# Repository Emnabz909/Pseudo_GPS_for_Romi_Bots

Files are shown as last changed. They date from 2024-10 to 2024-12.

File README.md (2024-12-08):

# Pseudo GPS for Romi Bots
Senior Project for Charlie Refvem by Emmanuel Baez, Gabriel Coria, Owen Guinane and Conor Schott

## Table of Contents
[Statement of Disclaimer](#statement-of-disclaimer)<br>
[Project Overview](#project-overview)<br>
[Concept Description and Justification](#concept-description-and-justification)<br>

## Statement of Disclaimer
Since this project is a result of a class assignment, it has been graded and accepted as a fulfillment of the course requirements. Acceptance does not imply technical accuracy or reliability. Any use of information in this report is at risk to the user. These risks may include catastrophic failure of the device or infringement of patent or copyright laws. California Polytechnic State University at San Luis Obispo and its staff cannot be held liable for any use or misuse of the project.   

## Project Overview
This project aims to develop a "pseudo-GPS" system that provides real-time, accurate location data to multiple Romi robots within a lab environment, since traditional GPS is ineffective indoors. Indoor localization technologies such as radar, ultrasonic sensors, and camera vision systems could offer valuable insights for this endeavor. Currently, ME 405 students work with Romi robots but lack access to absolute orientation and location data, which would enhance algorithm development. The design challenge is to create a prototype sensor to help students perform localization tasks more effectively. Key objectives include developing and testing a functional prototype by Fall 2024 if feasible, analyzing and documenting its accuracy, range, update rate, and latency, and providing comprehensive schematics and well-documented code to ensure the project can be continued seamlessly in the future. 

## Concept Description and Justification 
Mounted overhead, the camera captures images of the lab table, which are processed to generate a grid overlay in 2-dimensional space, facilitating precise localization and differentiation of objects. The device creates an origin point on the table, which it uses to measure Romi bots and obstacles relative to it. It constantly monitors Romi bots and obstacles within its field of view. Data such as grid representation and object positioning are handled by our microcontroller for processing. 

To aid the microcontroller with processing, we will develop custom libraries tailored to recognize specific objects in the environment, including the Romi robots, table, and obstacles. Instead of training models through Teachable Machine, we will use Aruco markers, which function similarly to QR codes, to identify and track each object. 

We are confident that our hardware will be able to meet the project specifications. By using trigonometry and the manufacturer-given data on the camera modules, we can estimate an accuracy of 0.55 mm per pixel for the Raspberry Pi Camera Module 3 and an accuracy of 1mm per pixel with the Raspberry Pi Camera Module 3, assuming a mounting height of 6.75ft above the table. This falls well-within our target accuracy of +- 5mm for Romi tracking.

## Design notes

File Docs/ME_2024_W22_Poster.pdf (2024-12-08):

# Pseudo GPS for Romi Bots

## Team members: Emmanuel Baez, Gabriel Coria, Owen Guinane, Conor Schott

B

# MECHANICAL ENGINEERING

The image above shows the camera setup, which will be mounted on the classroom roof. This location ensures the camera can see the entire space, allowing it to easily track the movement of the Romi robots.

The image above shows a Romi Robot with an ArUco marker attached to the top. This marker helps us track the robot’s location and movement, making it easier to monitor its actions and interactions in real-time.

This test demonstrates how ArUco markers can be used to track positions in space. One marker is set as the origin, while other markers are tracked based on their coordinates, calculated from the camera's view using pixel data. In this test, the markers remain stationary to show how their positions can be accurately identified and mapped.

## Testing for Position and Orientation

## Classroom Setup

## Romi with ArUco Marker

Our final design securely holds the Raspberry Pi and Pi Camera in place. The 3D-printed mount is designed to be easily attached to a ceiling tile using toggle bolts, ensuring a stable and adjustable installation.

## Final Design

## Conceptual Idea

## Camera Spec Analysis

## Problem Statement

To verify that our camera is capable of tracking within our +- 5mm accuracy target, we can use our Field of View (FOV) specifications provided by the camera manufacturer as well as the known height the system will be mounted to the ceiling to estimate the viewing area of the camera. If the viewing area can fully capture the table, then we can use the digital resolution of the camera as well as the viewing area to determine the number of mm per pixel. If this is less than 5mm, the camera will be suitable for this application.

The project involves using an overhead camera to monitor a lab table. The camera captures images, which are processed by a microcontroller to track objects relative to a defined origin on the table. Custom libraries will reference objects like the Romi bots and obstacles, with computer vision tools like the ArUco markers to improve object recognition.

Object localization are handled through OpenCV, which detects object contours and calculates their coordinates relative to the grid’s origin. The system uses ArUco markers placed on the Romi bots or obstacles for precise identification and orientation, improving localization accuracy. The system continuously captures video for real-time monitoring, with detected objects localized and used for movement control to avoid obstacles.

## List of Acknowledgement

### - Charlie Refvem

### - Dr. Amanda Emberley

### - Dr. John Ridgely

### - Dr. Jonathan Ventura

The Romi robots in the Cal Poly Mechatronics lab currently can't determine their exact position or orientation using their own sensors. To help develop more advanced technology, ME 405 instructor Charlie Refvem and his students need a system that can provide accurate, real-time location data for multiple Romi robots. This solution will improve how the robots track each other and communicate, ensuring high accuracy, precision, and fast updates over a wide range with minimal delay.

The lack of indoor localization technology limits ME 405 students’ ability to gather precise position data on the Romi robot, restricting their development of advanced algorithms.

## Objective

Distance Test @ Various Heights
| Computer | Actual | z [mm]
Run 1 | x [mm] | 86 | 81 | 15
| y [mm] | 369 | 370
Run 2 | x [mm] | 605 | 590 | 113
| y [mm] | 202 | 190
Run 3 | x [mm] | 536 | 534 | 50
| y [mm] | 378 | 380
Run 4 | x [mm] | 24 | 35 | 113
| y [mm] | 53 | 60
Run 5 | x [mm] | 117 | 122 | 50
| y [mm] | 460 | 463

Distance Test @ Constant Heights Markers placed on Romi (z = 105mm)
| | Computer | Actual
Run 1 | x [mm] | 310 | 296
| y [mm] | 95 | 85
Run 2 | x [mm] | 192 | 178
| y [mm] | 339 | 330
Run 3 | x [mm] | 232 | 225
| y [mm] | 144 | 150
Run 4 | x [mm] | 208 | 195
| y [mm] | 231 | 220
Run 5 | x [mm] | 141 | 135
| y [mm] | 232 | 215

Distance Test @ Constant Heights Markers placed on Romi (z = 0mm)
| | Computer | Actual
Run 1 | x [mm] | 7 | 0
| y [mm] | 392 | 361
Run 2 | x [mm] | 89 | 90
| y [mm] | 2 | 0
Run 3 | x [mm] | 139 | 137
| y [mm] | 46 | 42
Run 4 | x [mm] | 35 | 30
| y [mm] | 236 | 242
Run 5 | x [mm] | 455 | 443
| y [mm] | 248 | 255

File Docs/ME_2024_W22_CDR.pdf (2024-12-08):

Romi GPS | 1

Critical Design Review (CDR) report

# Pseudo GPS for Romi Critical Design Review

May 2, 2024

For Charlie Refvem

Team
Emmanuel Baez – embaez@calpoly.edu Gabriel Coria – gacoria@calpoly.edu Owen Guinane – oguinane@calpoly.edu Conor Schott – cjschott@calpoly.edu

College of Engineering
California Polytechnic State University, San Luis Obispo 2024

## Table of Contents

## Statement of Disclaimer

Since this project is a result of a class assignment, it has been graded and accepted as a fulfillment of the course requirements. Acceptance does not imply technical accuracy or reliability. Any use of information in this report is at risk to the user. These risks may include catastrophic failure of the device or infringement of patent or copyright laws. California Polytechnic State University at San Luis Obispo and its staff cannot be held liable for any use or misuse of the project.

## Four Panel Chart

Table 1. Four-Panel Chart
Project Overview
- Project Objective: Currently, the Romi robots used in the Mechatronics lab have no way of obtaining absolute orientation or location from onboard sensors. The Cal Poly ME 405 instructor, Charlie Refvem, and Mechatronics students need a way to deliver precise and real-time location data for multiple Romi robots for the development of better algorithms. Our aim is not just to improve tracking but also to enhance communication standards among multiple Romis by ensuring geolocation accuracy, precision, range, latency, and update rates.
- Documentation and Impact: The project involves comprehensive documentation, including detailed electrical schematics and code explanations.

Concept Description

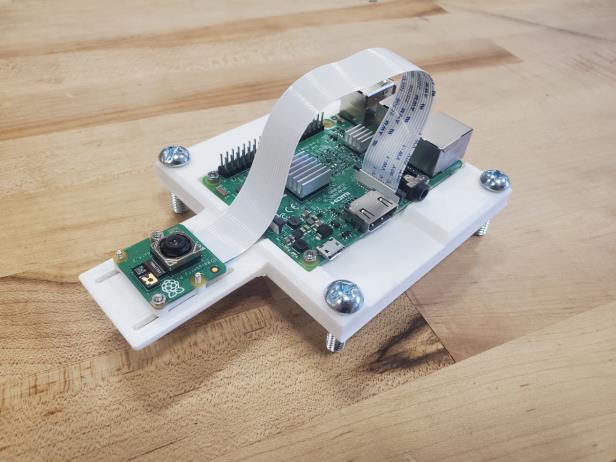
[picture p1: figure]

The idea with our structural prototype is to prove that our system will be able to detect the Romi bots as well as that it will properly mount to a ceiling tile. In the picture above is our Raspberry Pi and Camera Module wired together ready to be used.

Concept Justification

The decision to integrate camera technology into the project is based on its accuracy, providing precise locational data within ±5mm. The Raspberry Pi camera’s real-time data capabilities and fast update rate enable monitoring of multiple Romi robots. Additionally, the camera's cost-effectiveness and plentiful documentation online further supports its selection for enhancing tracking capabilities.

What’s Next

This quarter we will have to keep working on our software to get the detection to work, as well as implementing a grid system to help with the position of the Romi bots. We will perform multiple pass/fail tests on the detection and position and safety tests with our system mounted. The safety test for mounting the system will consist of FEA on our ceiling tile, and a shake test to see if the system will fall.

## Overview

We have finalized the concept selection and are currently expanding further iterations on our concept prototype. This report aims to describe our chosen concept, our reasoning behind it, and a table of the alternate solutions considered. In addition, this report also includes a preliminary analysis, a weighted design matrix, an updated Gantt chart, a design hazard matrix, and our references. We hope to get feedback on our reasoning for the sensor choice and on the housing system.

## Concept Description and Justification

For our system, we decided to use a Raspberry Pi with a camera to obtain absolute orientation and positional data. The basic layout is depicted in Figure 1 below.

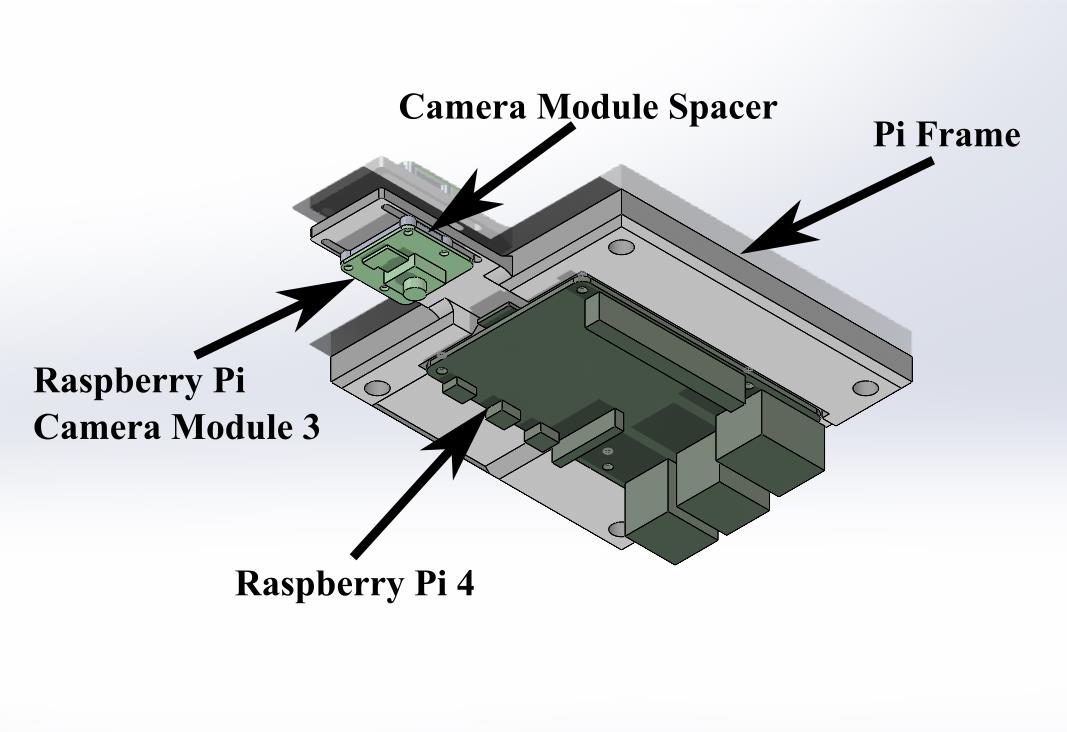
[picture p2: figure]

Figure 1. General layout of system

Mounted overhead, the camera captures images of the lab table, which are processed to generate a grid overlay in 2-dimensional space, facilitating precise localization and differentiation of objects. The device then creates an origin point on the table, which it will use to measure Romi bots and obstacles relative to it. It will constantly monitor Romis and obstacles within its field of view. Data, such as grid representation and object positioning will be handled by our microcontroller for processing. Through various algorithms, the microcontroller categorizes objects based on predefined characteristics and determines their relative locations with a precision of ±5mm, utilizing image processing techniques like object recognition and spatial mapping to track and locate Romis and obstacles in real-time, ensuring current and reliable tracking data.

The software integrates computer vision and machine learning techniques to detect Romis, obstacles, and the table. Initially, essential components such as the COCO dataset's class names and the SSD MobileNet V3 model configuration are imported. This setup enables the system to recognize a wide range of objects with high precision. Upon initialization, the detection model is configured with specific parameters for optimal performance. During operation, the software continuously captures frames from the overhead camera feed and undergoes object detection using the pre-trained SSD MobileNet V3 model. Detected objects are identified based on their confidence scores and class labels, and bounding boxes are drawn around them for visualization. Simultaneously, the software establishes a grid overlay on the detected table and defines an origin point, facilitating precise localization and measurement of objects within the environment. Coordinates of Romis and obstacles relative to the table's origin are then transmitted to the microcontroller for further processing and monitoring. Through the integration of object detection, grid generation, and coordinate calculation functionalities, the software ensures accurate detection and monitoring of Romis and obstacles.

## Safety

To ensure the safe operation of our system, several main concerns need to be addressed. The largest safety concern with our system comes with mounting. Because the system is roof-mounted, we need to design the system to be mounted securely and minimize the chance of falling out, due either to structural failure of mounting parts or by not fitting properly within a drop-down roof tile frame. To ensure this does not occur, we plan on performing finite-element analysis on the mounting hardware to verify that it can hold the entire weight of the system with a safety factor of 5. Minor safety considerations include adding fillets and chamfers to 3-D printed parts to eliminate sharp corners and edges which can cut the user when handling.

## Justification Table

Table 2. Justification Table

Spec # | Specification Title | Specification Description | Target (units) | Justification
1 | Total System Length | The system would prefer to be able to fit onto a Romi. | Romi Size | Currently, we plan to attach an ESP32 module to the Romi bots for communication. Our sponsor has approved.
2 | Total System Weight | The Romi will also have other sensors attached to it, so we would not want to encumber it further. | 2 lbs. | Currently, we have plans to attach an ESP32 module to the Romi bots for Communication, and our sponsor said it's okay.
3 | Field of View | The system should track a Romi placed on the classroom table. | 96x48 in. | The Raspberry Pi Camera 3 modules have a wide enough field of view to capture the table in its entirety, depending on the mounting distance.
5 | Data Transfer | The system should be able to transfer data at a high rate. | 6 Hz | The Raspberry Pi 4 that we purchased has the specs to transfer data at 6 Hz.
6 | Number of Romis being detected | The system should be able to track multiple Romis | 6 bots | Our tracking camera algorithm combined with the camera positioning will be able to track 6 Romis.
7 | Tracking Resolution | The system should be able to track the position of Romi. | +/- 5 mm | The Raspberry Pi Camera 3 modules will have enough resolution to track Romi position.
8 | Production Cost | The budget is $500. (could be higher) | $500 | We have an Excel that we put in every purchase to make sure we are within budget and notify our sponsor when we need to make a purchase.

## Appendix

## Updated Gantt Chart

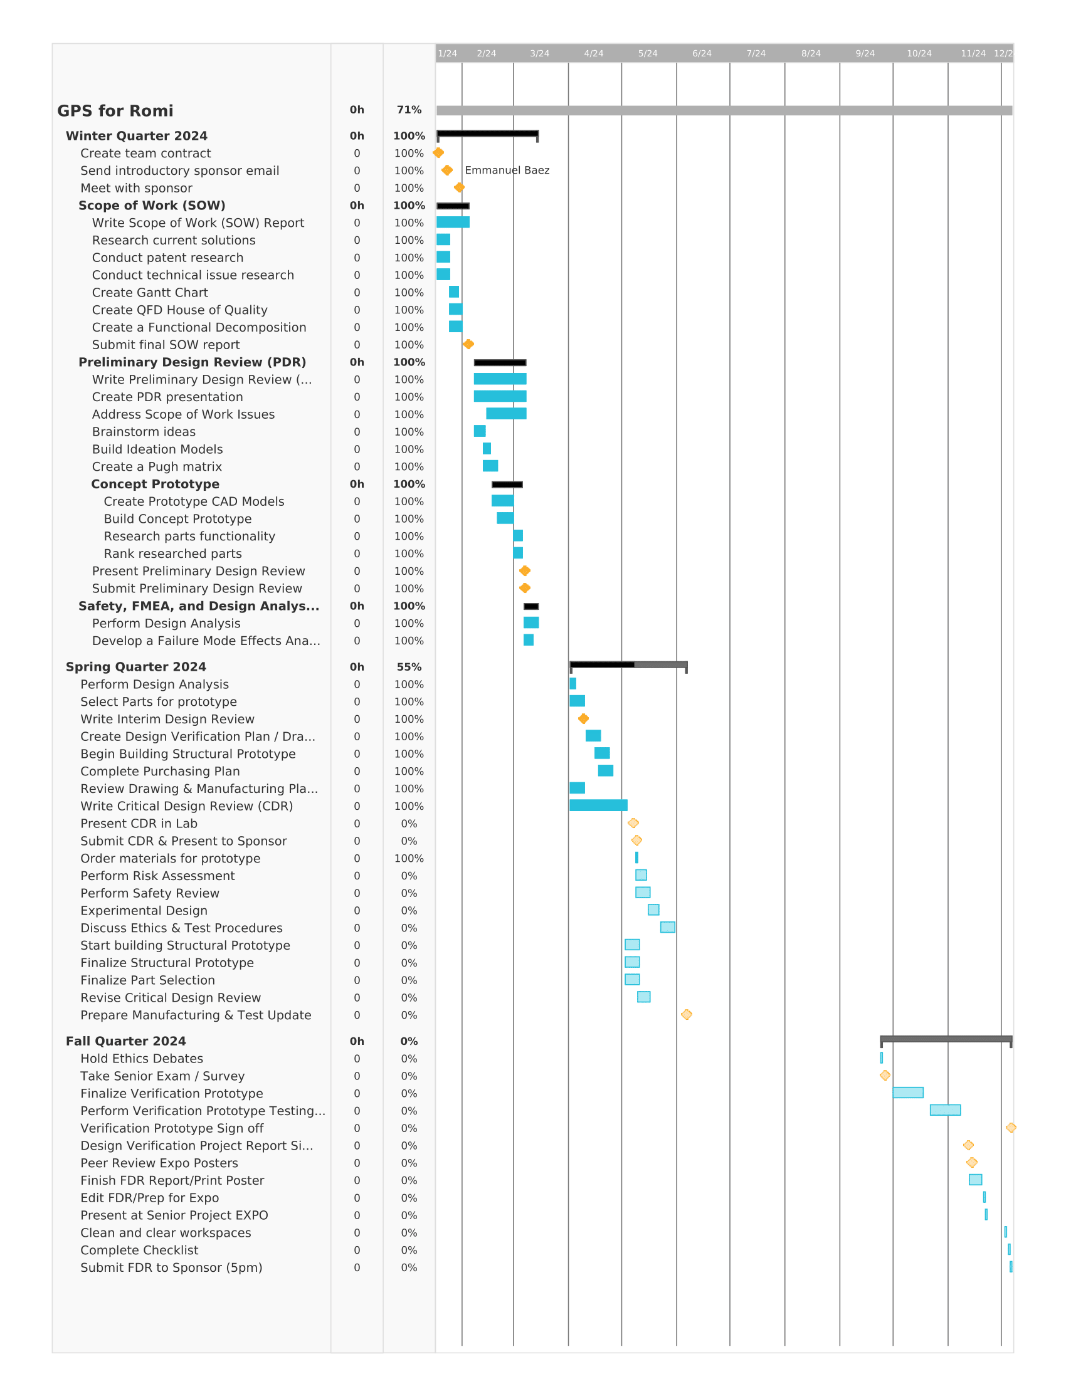
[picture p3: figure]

## Design Hazard Checklist

Table 4. Design Hazard Checklist Table

Y | N
| N | 1. Will any part of the design create hazardous revolving, reciprocating, running, shearing, punching, pressing, squeezing, drawing, cutting, rolling, mixing or similar action, including pinch points and sheer points?
| N | 2. Can any part of the design undergo high acceleration/deceleration?
| N | 3. Will the system have any large moving masses or large forces?
| N | 4. Will the system produce a projectile?
Y | | 5. Would it be possible for the system to fall under gravity creating injury?
Y | | 6. Will a user be exposed to overhanging weights as part of the design?
| N | 7. Will the system have any sharp edges?
| N | 8. Will any part of the electrical systems not be grounded?
| N | 9. Will there be any large batteries or electrical voltage in the system above 40 V?
| N | 10. Will there be any stored energy in the system such as batteries, flywheels, hanging weights or pressurized fluids?
| N | 11. Will there be any explosive or flammable liquids, gases, or dust fuel as part of the system?
| N | 12. Will the user of the design be required to exert any abnormal effort or physical posture during the use of the design?
| N | 13. Will there be any materials known to be hazardous to humans involved in either the design or the manufacturing of the design?
| N | 14. Can the system generate high levels of noise?
| N | 15. Will the device/system be exposed to extreme environmental conditions such as fog, humidity, cold, high temperatures, etc?
| N | 16. Is it possible for the system to be used in an unsafe manner?
| N | 17. Will there be any other potential hazards not listed above? If yes, please explain on reverse.

## Manufacturing Plan

Table 5. Manufacturing Plan table

Sub system | Component | Purchase (P) Modify (M) Build (B) | Raw Materials Needed to make/modify the part (only M & B) | Where/how procured? | Equipment and Operations anticipate using to make the component | Key limitations of this operation places on any parts made from it
Ceiling Mount | Ceiling Tile | M | Ceiling Tile | Provided by Wood Workshop at Cal Poly for use in Lab 192-118 | 11/16" Drill Bit, Cordless Drill to make holes that the threaded inserts will screw into. | n/a
| 1/4"-20 Zinc Plated Insert Nut | P | n/a | Purchased at Home Depot | n/a | n/a
Housing | Main Housing | B | PLA Plastic | 3D printed | 3D Printer to create the housing, M2.5 x .45, 1/4"-20 tap drill bit and a tap s to create internal threads on the large outer holes and small inner holes. Deburring may be necessary after tapping. | Small size may prevent M2.5 holes from printing properly. Additional drilling may be required
| 1/4"-20 1" Machine Screws | P | n/a | Purchased at Home Depot | n/a | n/a
| M2.5 10mm Screws | P | n/a | Purchased from Amazon | n/a | n.a
| M2 10mm screws | P | n/a | Purchased from Amazon | n/a | n/a
Microcontrolle r | Raspberry Pi 4 Model B | P | n/a | part already provided by sponsor (Adafruit) | n/a | n/a
| Micro HDMI Cable | P | n/a | part already provided by sponsor (Adafruit) | n/a | n/a
| SD card | P | n/a | part already provided by sponsor (Adafruit) | n/a | n/a
| Heat Sink | P | n/a | part already provided by sponsor (Adafruit) | n/a | n/a
| Power Supply | P | n/a | part already provided by sponsor (Adafruit) | n/a | n/a
Camera | Raspberry Pi Camera Module 3 | P | n/a | part already provided by sponsor | n/a | n/a
| Camera Spacer | B | PLA Plastic | 3D printed | 3D Printer to create the part | Small Size may prevent M2 holes from printing to size. Screws may have to be threaded through.

Manufacturing Steps
Ceiling Tile Assembly
Ceiling Tile (110)
11/16” Drill Bit with Cordless Drill
1. Drill four holes that are 11/16” in diameter on the top (floor-facing) side of the ceiling tile to allow the threaded inserts to screw in.
2. Screw 1/4”-20 Zinc Plated inserts into drilled holes. These will connect the main housing to the ceiling tile.

Housing Assembly
Main Housing (210)
3D Printer
1. Using the provided file “MainHousing.STL”, use a 3D printer to print the housing. Refer to printer documentation for instructions on how to print an STL file.
1/4"-20 Tap drill bit and Tap
2. On the larger outer 4 holes and center hole, tap these holes all the way through. These holes will secure the housing to the ceiling tile.
M2.5 x 45 Tap drill bit and Tap
3. On the smaller inner 4 holes, tap these holes all the way through. These will be used to secure the Raspberry Pi 4 to the housing.

Camera Assembly
Camera Spacer (2320)
3D Printer
1. Using the provided file “CamSpacer.STL”, use a 3D printer to print the spacer. Refer to printer documentation for instructions on how to print an STL file.

Assembly instructions
1. Screw the Camera Spacer (2320) to the slots of the Main Housing (210) using four M2 10mm Machine Screws (250) so that camera spacer is on the top side of the part and the threads are facing upward.
2. Insert the MicroSD Card (2220) into the Raspberry Pi 4 (2210) to make the Microcontroller Assembly.
3. Screw the Microcontroller Assembly (220) into the main housing with four M2.5 10mm Machine Screws (250) until it is finger tight. Over-tightening the screw may cause damage to the board.
4. Insert the Raspberry Pi Camera Module 3 (2310) on the threads of the M2 Machine Screws. Use M2 Nuts (270) to secure the camera to the spacer.
5. Connect the camera module to the Raspberry Pi 4 using the module’s ribbon cable.
6. Use a 6mm hex key to screw the threaded inserts (120) into the ceiling tile to make the Ceiling Tile Assy (10).
7. Using the four 1/4” – 20 1” Machine Screws (240), screw the Main Housing to the holes in the Ceiling Tile Assy (10) to create the Final Assembly (1).
8. Install the Final Assembly in place of a similar ceiling tile or empty ceiling tile frame over desired tracking area.
9. Connect Power Supply (31) and Micro HDMI (30) cables as needed.

## Design Manufacturing Plan

Table 3. Design Verification Plan Table
Planned Test | What it will test (user need or specific spec, whichever is most applicable for your project and sponsor) | Required resources
Detection Test | Test to see if the code runs with no errors and if the camera displays a picture while detecting objects. | Raspberry Pi, camera, computer
Ceiling Mount Test | Testing to inspect whether the hardware will stay on the ceiling | Ceiling tile, Raspberry Pi, Housing, Camera
Rate of Transfer test | Test to see how fast the data from the Raspberry Pi is transferred to a computer. | Raspberry Pi, Computer
Fitment and Weight test | Test to ensure that ESP32 module will fit comfortably on the Romi robots without encumbering them | ESP32 Module, Romi Robots
Resolution test | Test to determine how accurate the camera can track a single Romi Robot with a target accuracy of | Romi Robot, Final assembly, computer
Swarm detection test | Test to ensure that system is capable of tracking multiple Romi robots simultaneously without issues. | Romi Robots, Final Assembly, Computer

## Budget

Table 6. Budget Chart

### Romi Budget Plan

Part | Cost ($)
Micro HDMI to HDMI cable | 8.95
Raspberry Pi Camera Module 3 Standard - 12MP Autofocus | 25
Raspberry Pi 4 model B-8GB RAM x2 | 150
Official Raspberry Pi Power Supply 5.1V 3A with USB C | 7.95
SD/MicroSD Memory Card - 16GB Class 10 - Adapter Included | 19.95
Official Raspberry Pi 4 Case Fan and Heatsink | 5
Parts Total | 216.85
Initial Budget | 500
Current Budget | 283.15

## Idented Bill of Materials

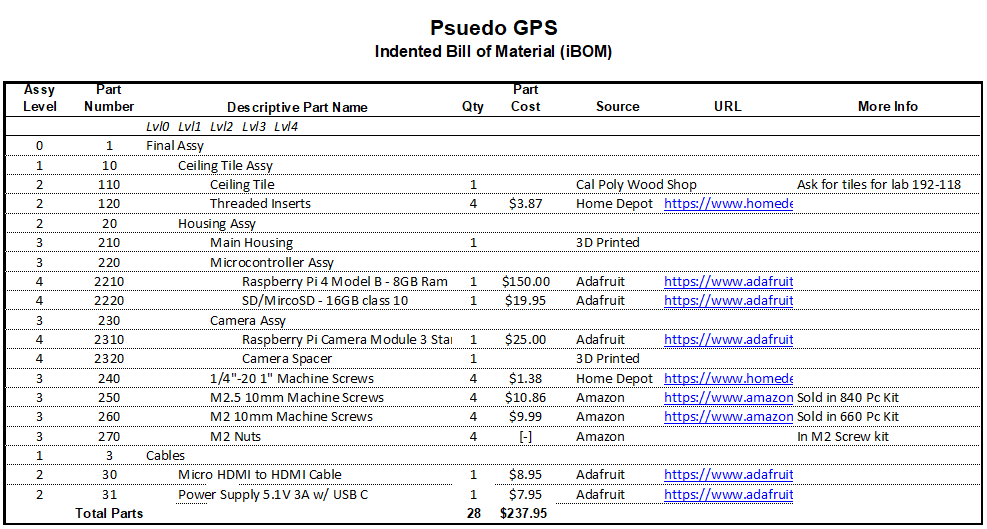
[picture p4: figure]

Figure 2. Indented Bill of Materials (iBOM)

## Supporting Evidence

We can confirm that our field of view and tracking resolution will meet our specifications by performing an analysis of the camera’s field of view. For a camera, we have two types of viewing distances that define our viewing area, horizontal distance Dhor and vertical distance Dvert. In our desired configuration where the camera system is mounted to the roof and facing down, we can calculate the viewing area using trigonometry.

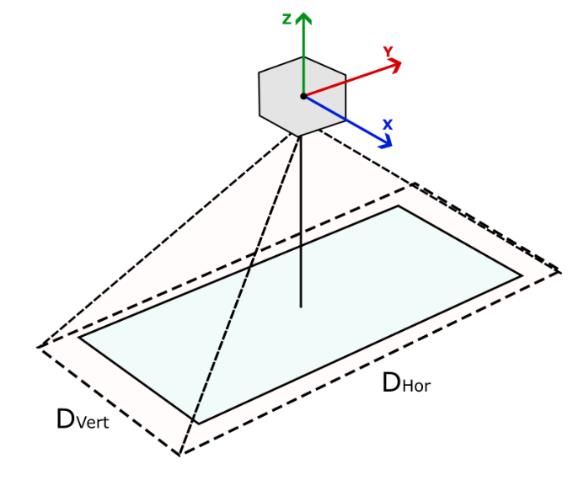
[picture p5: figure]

Figure 3. 3D Sketch of camera setup.

Camera manufacturers specify the horizontal and vertical angles for the field of view for any given lens which we’ll define as HFOV for the horizontal field of view and VFOV for the vertical field of view. Let’s take the case of the horizontal field of view. Assuming a perfectly centered camera, we can model it as a symmetrical triangle of angle HFOV, height Hmount, and distance Dhor. Hmount will be the height at which the system is mounted above the table.

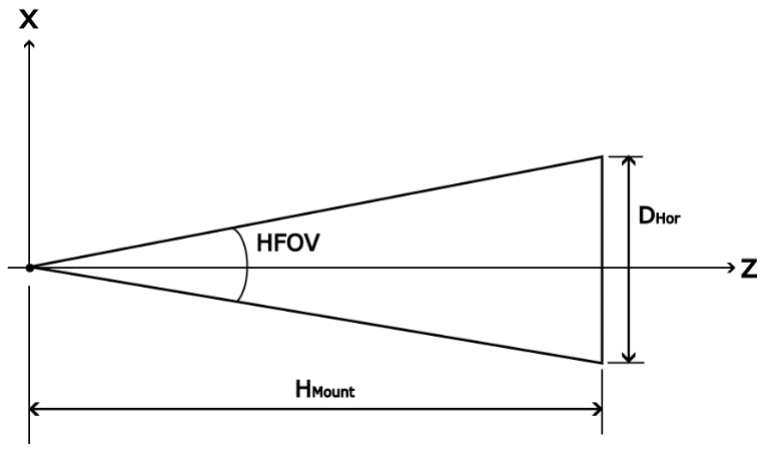
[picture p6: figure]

Figure 4. Viewing triangle of camera for horizontal distance

Since the triangle is isosceles, we can split it into two identical right triangles with half the angle and horizontal distance.

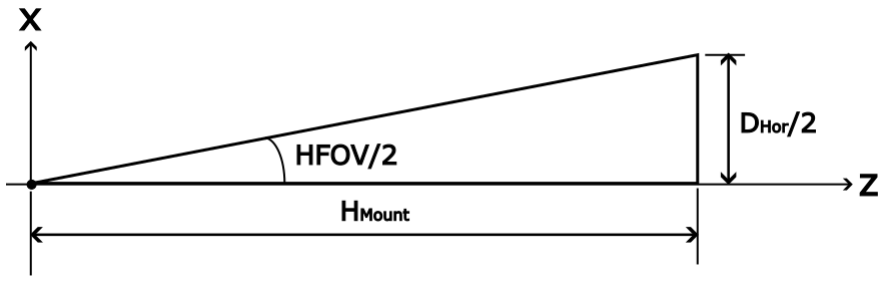
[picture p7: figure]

Figure 5. Half of viewing triangle. Trigonometry can now be used to solve for distance.

Using trigonometry, we obtain
tan (

HFOV
2

) =

(DHor/2)

(Hmount)
Rearranging the equation,

DHor = 2Hmount tan (

HFOV
2

)

Solving for the vertical distance DVert follows a similar process, so similar equation can be used.
DVert = 2Hmount tan (

VFOV
2

)

To track the whole table, the camera must have a vertical viewing distance of at least 4 feet and a horizontal viewing distance of 8 feet. Using these two distances, we can calculate the viewing area of the camera.
AView = DHor ∗ DVert
Finally, by dividing the viewing area by the pixel count, we can determine the area of each pixel in the image, which will be our tracking resolution area.

Apix =

AView
# ofPixels

A pixel is a square, so using the area of the pixel, we can determine the pixel width, which will be our tracking resolution.
Wpix = √Apix

Now that we have our basic equation, we can substitute our values to determine if our cameras will meet specifications. Measurements taken in the lab give us a maximum mounting height of 7 ft above the table. Accounting for the fact that our camera will not sit flush with the drop-down ceiling, we can assume a reasonable mounting distance of 6.25 ft above the table. To streamline the process of calculating viewing areas, we used an Excel worksheet to run the calculations

Table 7. Camera Calculation
Camera /Lens | Resolution | HFOV | VFOV | Dhor | Dvert | Aview | Apix | Wpix
[pixels] | [deg] | [deg] | [ft] | [ft] | [ft^2] | [mm^2] | [mm^2 ] | [mm]
Raspberry Pi Camera Module 3 | 1.19E+07 | 66 | 42 | 8.12 | 4.80 | 39.0 | 3.62E+0 6 | 0.30 | 0.55
Raspberry Pi Camera Module 3 Wide | 1.19E+07 | 102 | 67 | 15.44 | 8.27 | 127.7 | 1.19E+0 7 | 1.00 | 1.00

From our analysis, it appears that both the Raspberry Pi camera module 3 and Raspberry Pi Camera Module 3 wide will both meet our design specifications.

The ESP32 effectively communicates with our Pi4’s Wi-Fi module, ensuring seamless connectivity. Its integration with the Romi Nucleo board, equipped with GPIO pins, ADC, and PWM, facilitates data transmission to and from the Pi4. With low power consumption, especially when powered by the Nucleo, it enables smooth continuous tracking and monitoring tasks. Costing between $10 to $15, the ESP32 offers a cost-effective solution. Its compact dimensions (55mm x 27.9mm x 25mm) and lightweight construction (less than 1 ounce) ensure minimal impact on the Romi's weight distribution.

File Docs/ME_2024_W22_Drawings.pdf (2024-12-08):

# Pseudo GPS for Romi Drawing & Specification Package

May 10, 2024

For Charlie Refvem

Team

Emmanuel Baez – embaez@calpoly.edu

Gabriel Coria – gacoria@calpoly.edu

Owen Guinane – oguinane@calpoly.edu

Conor Schott – cjschott@calpoly.edu

College of Engineering

California Polytechnic State University, San Luis Obispo

2024

# Indented Bill of Materials

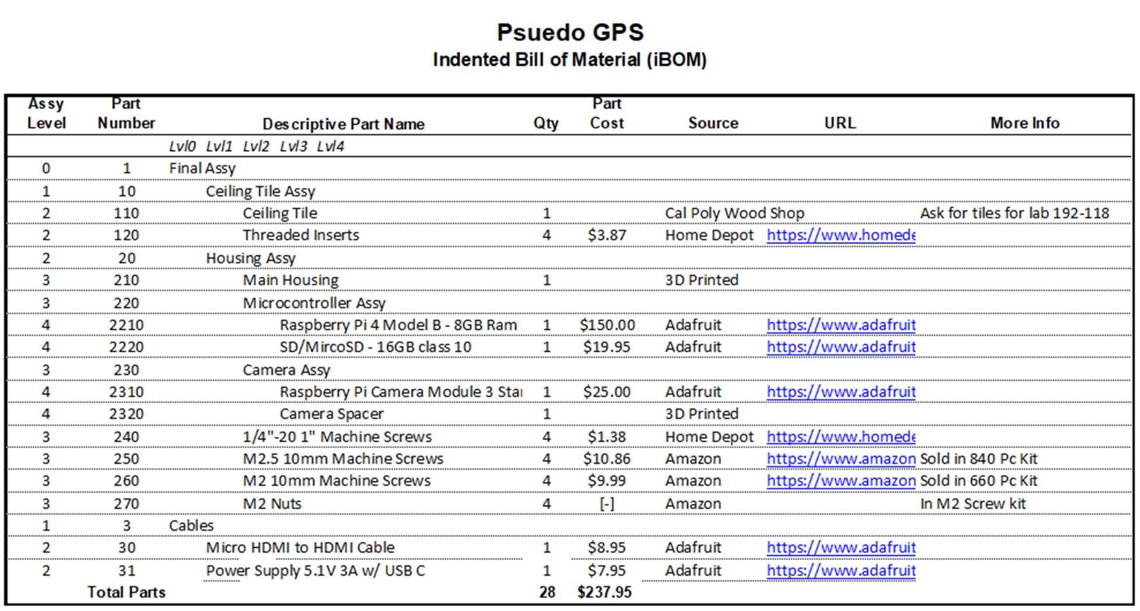
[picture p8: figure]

# Purchased Parts Table

Part # | Part Name | Vendor | Vendor's Part # | Price | Manuf. | Manuf. Part # | Key Features/ Specs | URL
120 | 1/4"-20 Zinc Plated Insert Nut | Home Depot | 20427422 2 | $3.87 | Everbilt | 801884 | 1/4" Diameter, 20 TPI, 3/4" Depth, Steel, Zinc Plated | https://www.homedepot.com/p/Everbilt-1-4-in-20-Zinc-Plated-Insert-Nut-4-Pack-801884/204274222
2210 | Raspb erry Pi 4 Mode l B | Adafruit | 4564 | $150. 00 | Raspber ry Pi | N/A | Microcontrolle r | https://www.adafruit.com/product/4564
2220 | 16GB Micro SD Card | Adafruit | 2693 | $19.9 5 | SanDisk | N/A | 16GB MicroSD card | https://www.adafruit.com/product/2693
2310 | Raspb erry Pi Came ra Modu le 3 | Adafruit | 5657 | $25.0 0 | Raspber ry Pi | N/A | 12MP, | https://www.adafruit.com/product/5657

240 | 1/4"-20 1" Mach ine Screw s | Home Depot | 20427464 4 | $1.38 | Everbilt | 803481 | 1/4" Diameter, 20 TPI, 1" Length, Steel, Zinc Plated, Round head philips machine screw | https://www.homedepot.com/p/Everbilt-1-4-in-20-x-1-in-Zinc-Plated-Combo-Round-Head-Machine-Screw-4-Pack-803481/204274644
250 | M2.5 10m m Mach ine Screw s | Amazon | B0CRRC YZHS | $10.8 6 | qiwuhai | N/A | M2.5, 304 Stainless Steel, Lengths ranging from 4-25mm, 40 screws for each size, half flathead, half hex button | https://www.amazon.com/dp/B0CRRCYZHS/ref=twister_B0CHMKL1DF?_encoding=UTF8&th=1
260 | M2 10m m Mach ine Screw s | Amazon | B0B93G1 H9L | $9.99 | Kadrick | N/A | M2, 304 Stainless Steel, Lengths ranging from 4mm to 16mm, 660 pc total | https://www.amazon.com/Kadrick-Assortment-Button-Stainless-Washers/dp/B0BX96SMW4?ref_=ast_sto_dp&th=1&psc=1
270 M2 | Nuts | Amazon | N/A | N/A | Kadrick | N/A | Comes in Kadrick M2 Kit, 220 pc count
30 | Micro HDM I to HDM I Cable | Adafruit | 1322 | $8.95 | Adafruit | N/A | 2 meters length, HDMI 1.3 to MicroHDMI | https://www.adafruit.com/product/1322
31 | Powe r Suppl y 5.1V 3A w/ USB C | Adafruit | 4298 | $7.95 | Raspber ry Pi | N/A | 1.5 meters length, 5.1V, 3A Output, USB-C | https://www.adafruit.com/product/4298

# Main Assembly Drawing

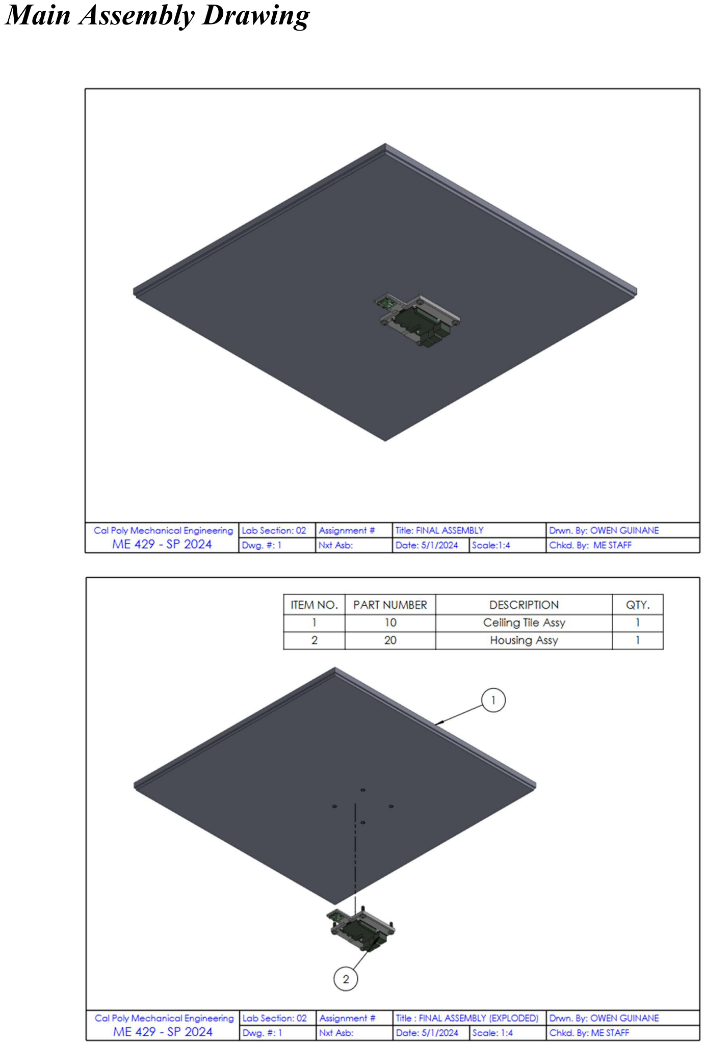
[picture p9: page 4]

# Ceiling Tile Assy

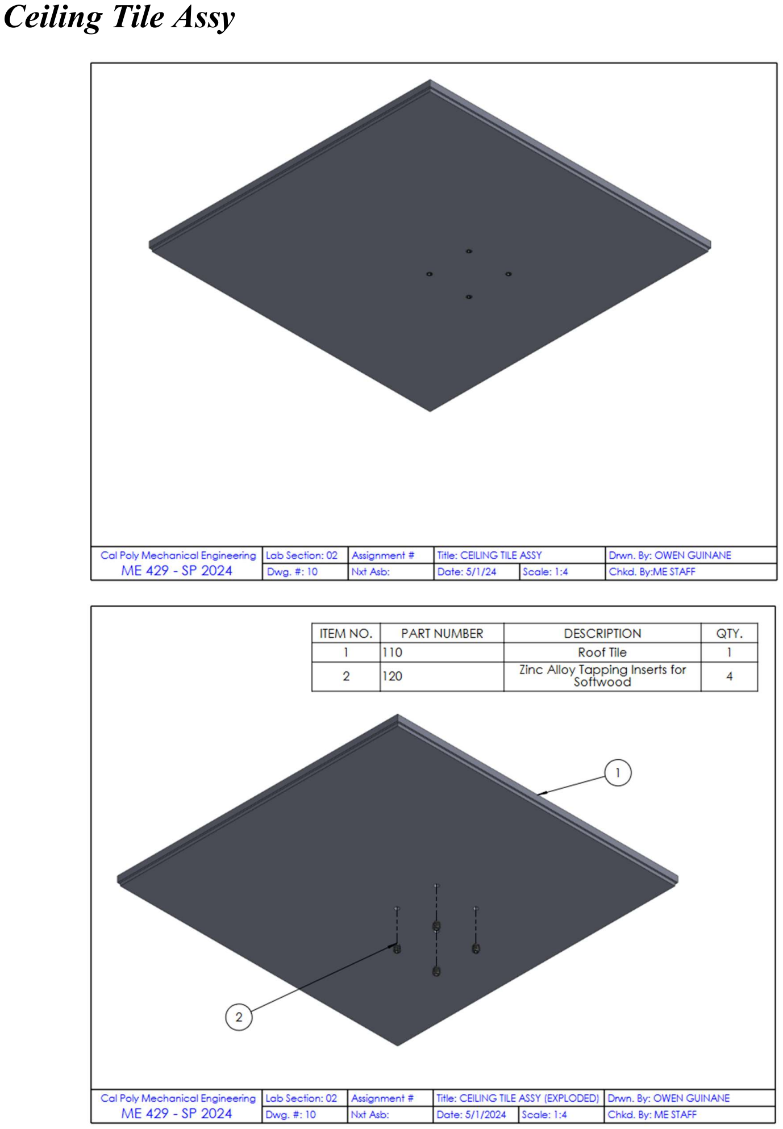
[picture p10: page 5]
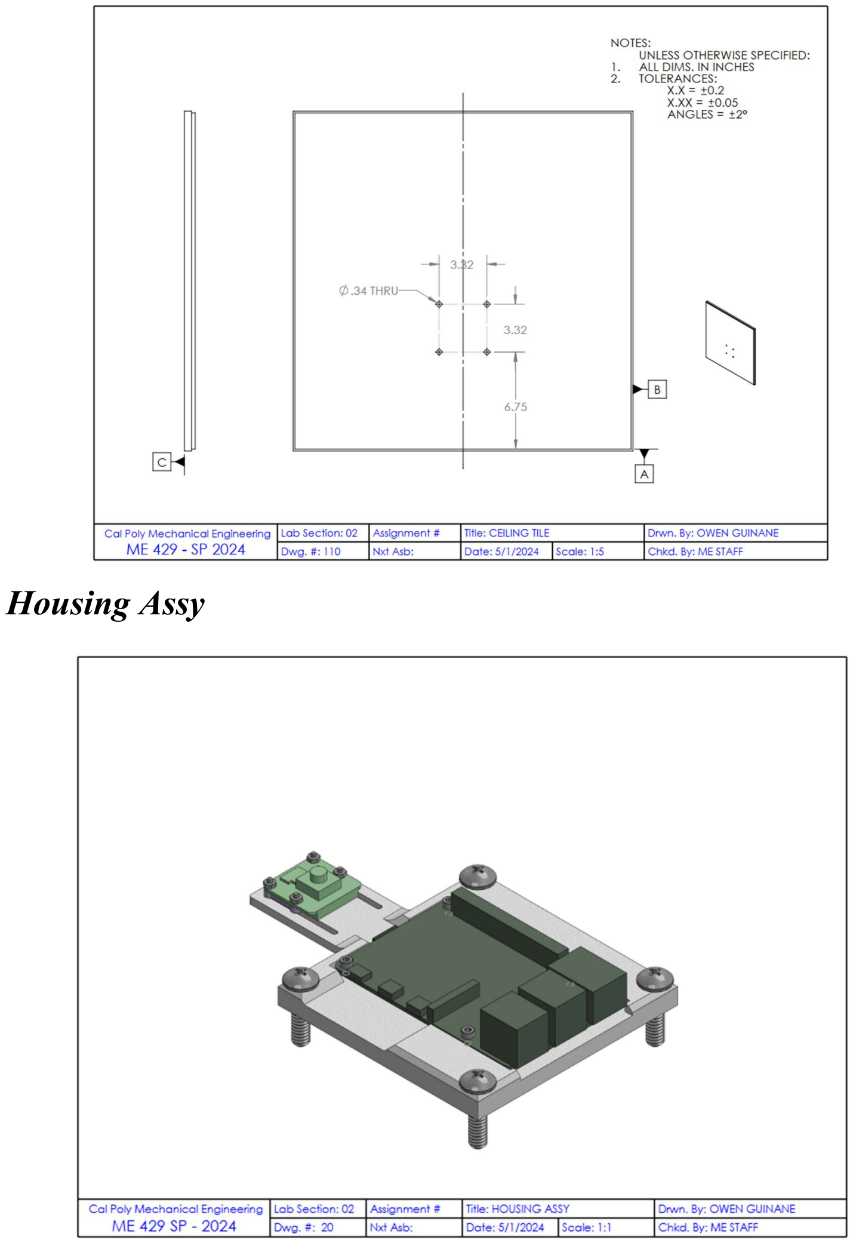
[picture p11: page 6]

# Housing Assy

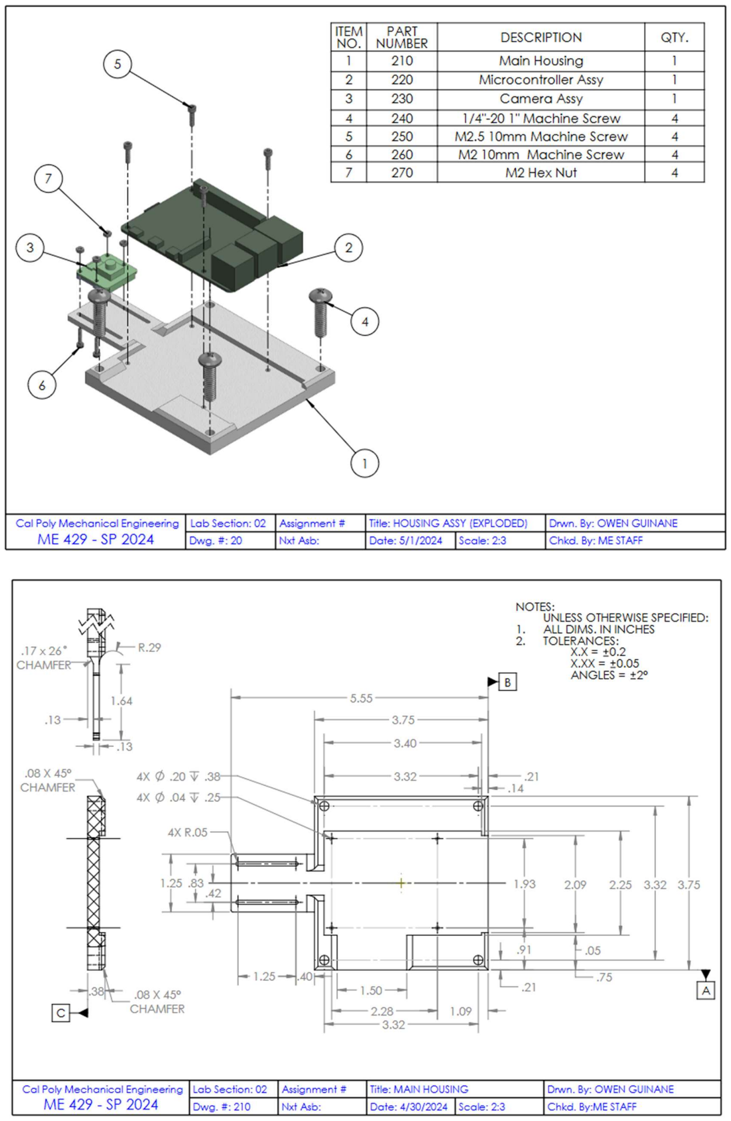
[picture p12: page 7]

# Microcontroller Assy

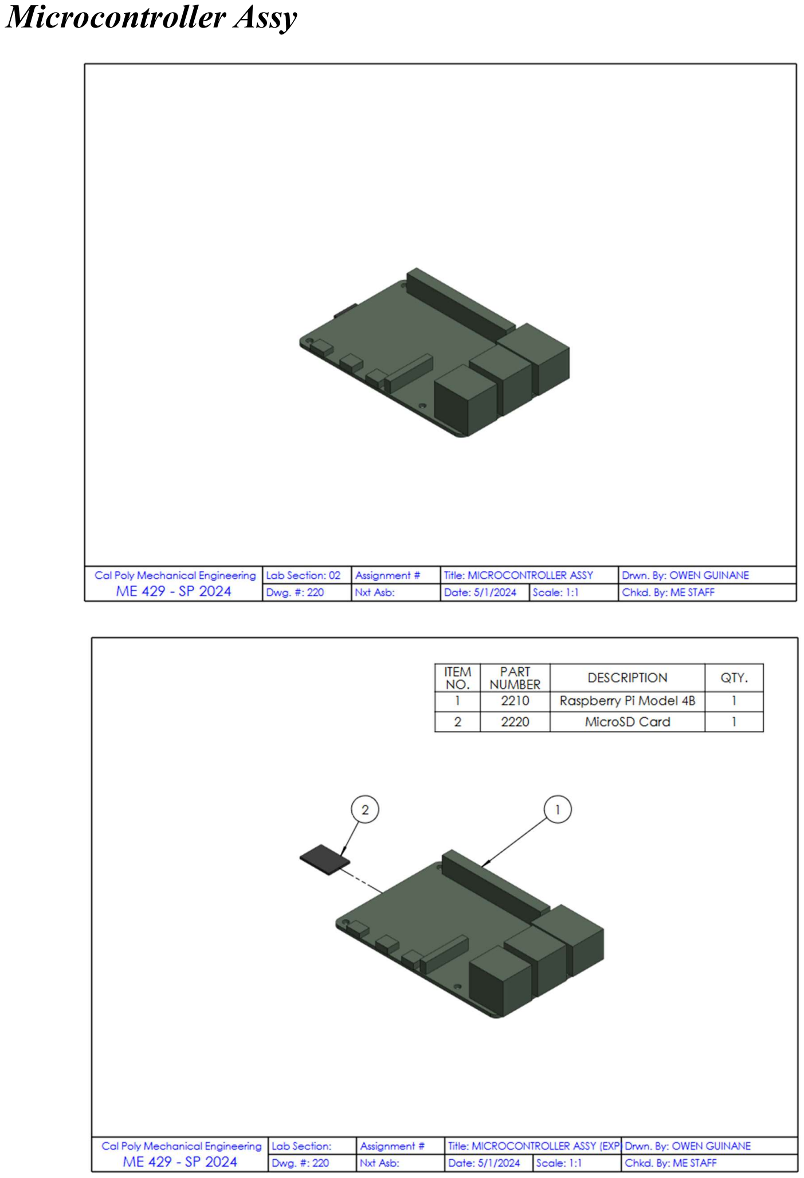
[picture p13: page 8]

# Camera Assembly

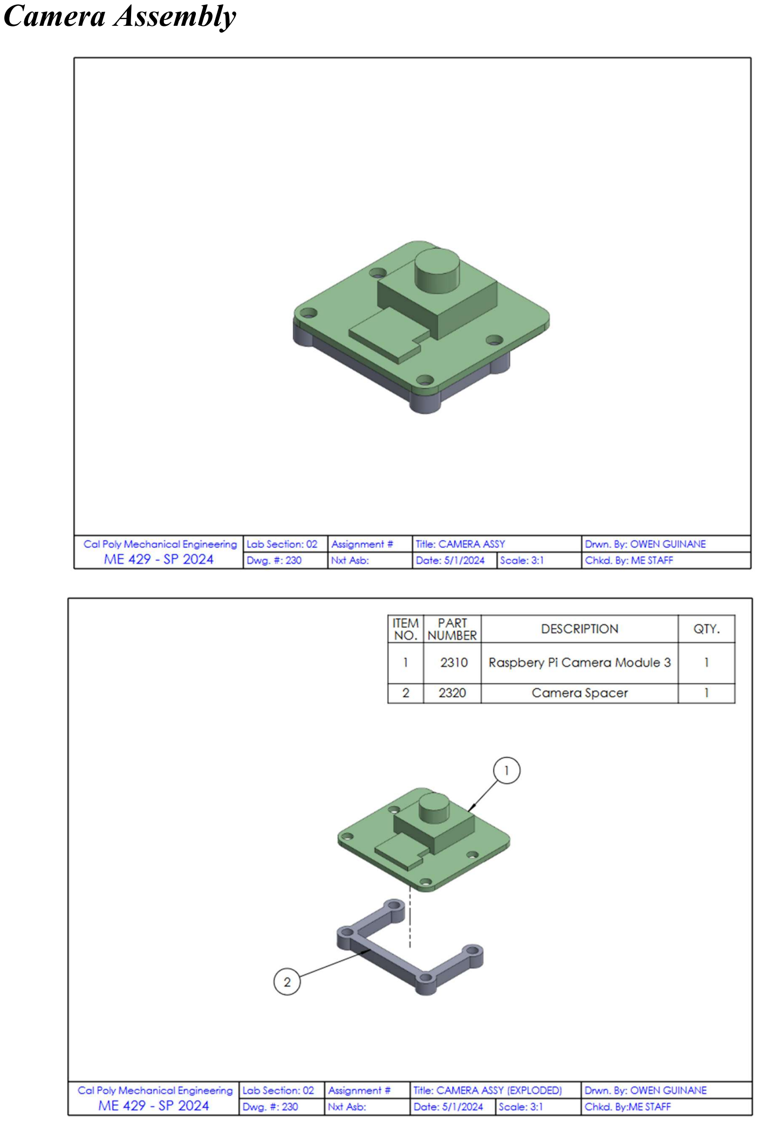
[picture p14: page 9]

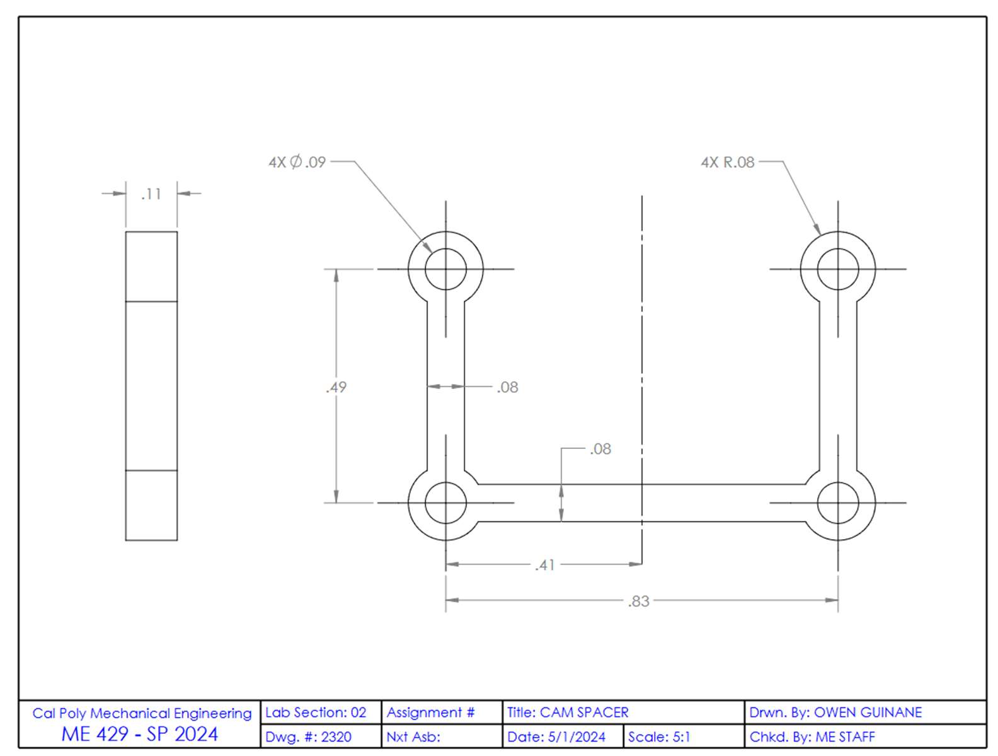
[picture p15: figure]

# Manufacturing Steps

Ceiling Tile Assembly

Ceiling Tile (110)

11/16” Drill Bit with Cordless Drill

1. Drill four holes that are 11/16” in diameter on the top (floor-facing) side of the ceiling tile to allow the threaded inserts to screw in.
2. Screw 1/4”-20 Zinc Plated inserts into drilled holes. These will connect the main housing to the ceiling tile.

Housing Assembly

Main Housing (210)

3D Printer

1. Using the provided file “MainHousing.STL”, use a 3D printer to print the housing. Refer to printer documentation for instructions on how to print an STL file.
1/4"-20 Tap drill bit and Tap
2. On the larger outer 4 holes and center hole, tap these holes all the way through. These holes will secure the housing to the ceiling tile.
M2.5 x 45 Tap drill bit and Tap
3. On the smaller inner 4 holes, tap these holes all the way through. These will be used to secure the Raspberry Pi 4 to the housing.

Camera Assembly

Camera Spacer (2320)

3D Printer

1. Using the provided file “CamSpacer.STL”, use a 3D printer to print the spacer. Refer to printer documentation for instructions on how to print an STL file.

# Assembly instructions

1. Screw the Camera Spacer (2320) to the slots of the Main Housing (210) using four M2 10mm Machine Screws (250) so that camera spacer is on the top side of the part and the threads are facing upward.
2. Insert the MicroSD Card (2220) into the Raspberry Pi 4 (2210) to make the Microcontroller Assembly.
3. Screw the Microcontroller Assembly (220) into the main housing with four M2.5 10mm Machine Screws
(250) until it is finger tight. Over-tightening the screw may cause damage to the board.
4. Insert the Raspberry Pi Camera Module 3 (2310) on the threads of the M2 Machine Screws. Use M2 Nuts
(270) to secure the camera to the spacer.
5. Connect the camera module to the Raspberry Pi 4 using the module’s ribbon cable.
6. Use a 6mm hex key to screw the threaded inserts (120) into the ceiling tile to make the Ceiling Tile Assy (10).
7. Using the four 1/4” – 20 1” Machine Screws (240), screw the Main Housing to the holes in the Ceiling Tile Assy (10) to create the Final Assembly (1).
8. Install the Final Assembly in place of a similar ceiling tile or empty ceiling tile frame over desired tracking area.
9. Connect Power Supply (31) and Micro HDMI (30) cables as needed.

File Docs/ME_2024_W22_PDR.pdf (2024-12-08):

# Pseudo GPS for Romi Preliminary Design Review

February 20, 2024

For Charlie Refvem

Team

Emmanuel Baez – embaez@calpoly.edu

Gabriel Coria – gacoria@calpoly.edu

Owen Guinane – oguinane@calpoly.edu

Conor Schott – cjschott@calpoly.edu

College of Engineering

California Polytechnic State University, San Luis Obispo

2024

## Statement of Disclaimer

Since this project is a result of a class assignment, it has been graded and accepted as a fulfillment of the course requirements. Acceptance does not imply technical accuracy or reliability. Any use of information in this report is at risk for the user. These risks may include catastrophic failure of the device or infringement of patent or copyright laws. California Polytechnic State University at San Luis Obispo and its staff cannot be held liable for any use or misuse of the project.

## Table of Contents

## Four Panel Chart

Table 1. Four-Panel Chart for Preliminary Design Review

Project Overview

- Project Objective: Currently, the Romi robots used in the Mechatronics lab have no way of obtaining absolute orientation or location from onboard sensors. The Cal Poly ME 405 instructor, Charlie Refvem, and Mechatronics students need a way to deliver precise and real-time location data for multiple Romi robots for the development of better algorithms. Our aim is not just to improve tracking but also to enhance communication standards among multiple Romis by ensuring geolocation accuracy, precision, range, latency, and update rates.
- GPS Prototype Goals: Provide precise, real-time location data for multiple mobile robots, improving tracking and communication standards.
- Documentation and Impact: The project involves comprehensive documentation, including detailed electrical schematics and code explanations.

Concept Description

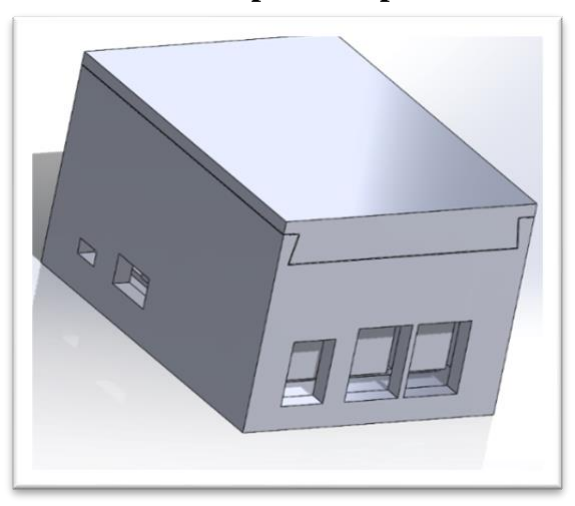
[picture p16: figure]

The idea is that this housing will be able to house our Raspberry Pi 4, our camera, and any other components we would be using. Currently, our components like wires and Raspberry Pi would be within the box, while the camera sensor would be mounted on top of the housing. The housing includes hole cutouts that could be used for USB and power cables if they may need to be accessed.

We ran a couple of tests with this prototype, such as placing our system overlooking a lab table and comparing where the best placement would be. From here, we would write code to detect the Romi bots once they start navigating the table.
Concept Justification

The decision to integrate camera technology into the project is based on its accuracy, providing precise locational data within ±5mm. The Raspberry Pi camera’s real-time data capabilities and fast update rate enable monitoring of multiple Romi robots. Additionally, the camera's cost-effectiveness and plentiful documentation online further supports its selection for enhancing tracking capabilities.

What’s Next

We will continue to develop our concept prototype, perform design analysis, and do a safety and failure mode effects analysis as the winter quarter ends. In the upcoming Spring quarter, we will generate a parts list and refine our model for the critical design review.

## Overview

We have finalized the concept selection and are currently expanding further iterations on our concept prototype. This report aims to describe our chosen concept, our reasoning behind it, and a table of the alternate solutions considered. In addition, this report also includes a preliminary analysis, a weighted design matrix, an updated Gantt chart, a design hazard matrix, and our references. We hope to get feedback on our reasoning for the sensor choice and on the housing system.

## Concept Description and Justification

Our decision to shift towards a camera-based tracking system stems from its effectiveness in meeting our project requirements. Cameras operate by exposing an imaging sensor to light for a brief period, and we can use the image captured to achieve our goal of delivering precise real-time location data for multiple Romis within the Mechatronics lab. For our hardware selection, we have opted to use the Adafruit Raspberry Pi High-Quality Camera with an M12 Lens mount as our primary sensor as shown in Table 1.

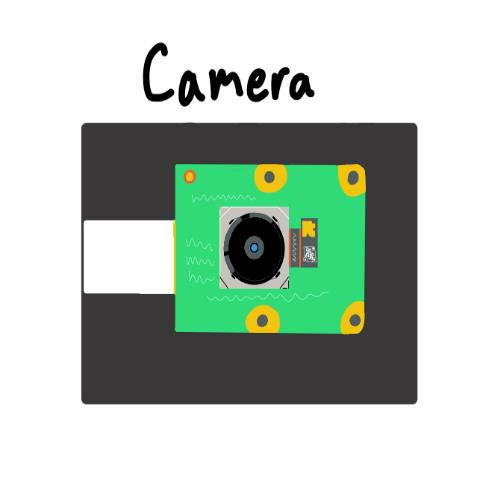
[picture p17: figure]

Figure 1. Adafruit Raspberry Pi High-Quality Camera with an M12 Lens

This camera offers adequate resolution, fits within our budget, and provides the flexibility of swappable lenses. Through the ribbon cable port on the Raspberry Pi 4, we can securely connect the camera to our existing microcontroller setup, while power can be conveniently supplied from a nearby outlet. As shown in Figure 2, the operational concept involves capturing images of the lab environment and processing them to create a grid representation of the table's surface, enabling precise categorization of Romis versus obstacles with a precision of ±5mm.

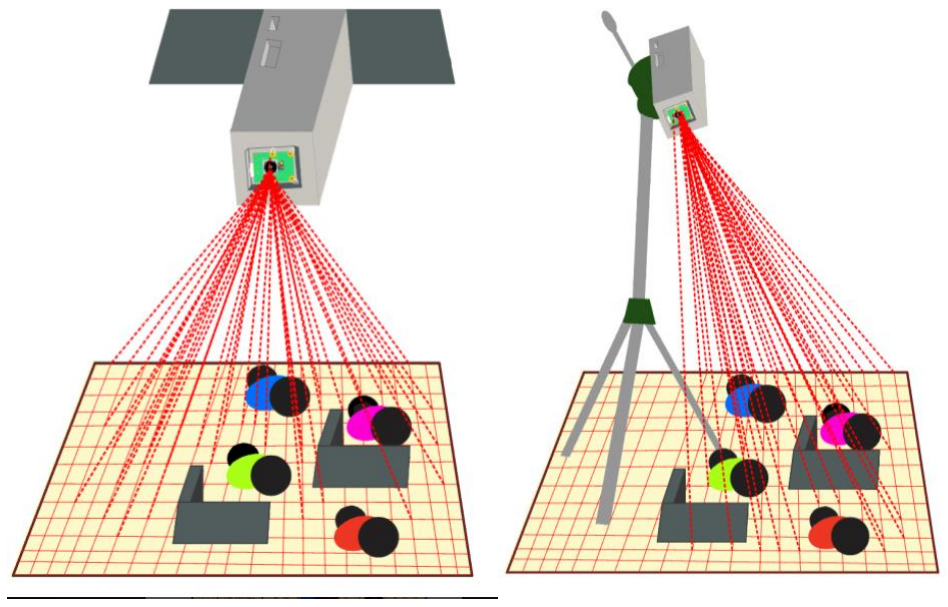
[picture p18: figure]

Figure 2. Tripod and ceiling-mounted configurations of the camera-based camera solution.

Mounted overhead, the camera captures images of the lab table, which are then processed to generate a grid overlay in 3-dimensional space, facilitating precise localization and differentiation of objects within the environment. This can be achieved by creating an origin point on the table and calibrate our system to measure the Romi bots and obstacles relative to it. As a result, we have two configurations for the Romis. The tripod configuration will be used primarily for testing code as it can be easily removeable in a lab environment. For the final product, we plan on creating a ceiling mounted configuration so it can be used for future classes. After creating an origin and grid representation, the camera continually monitors the movement of Romis and obstacles within its field of view, ensuring accurate detection and recording of any changes. The camera then sends this data, including the grid representation and object positions, to the microcontroller for processing. Through various algorithms, the microcontroller analyzes the data to categorize objects based on predefined characteristics and determines their relative locations with a precision of ±5mm. This process utilizes image processing techniques such as object recognition and spatial mapping to track and locate Romis and obstacles in real-time, ensuring that the tracking data remains current and reliable throughout the operation.

In summary, a camera-based tracking system effectively meets our project requirements by providing precise real-time location data for Romis in 3-dimensional space within the Mechatronics lab environment.

# Alternative Solutions Table

Table 2. Alternative Solutions Considered
Solution Name | Description | Justification
Marvel Mind

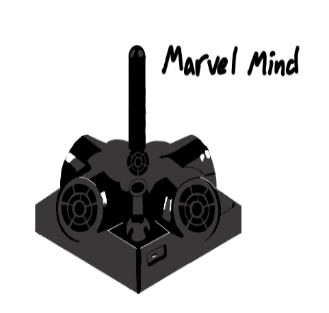
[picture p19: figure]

Indoor positioning and
navigation system. Supports autonomous indoor navigation for mobile robots, vehicles, and drones.

Marvel Mind utilizes GPS technology in their Starter Set Super-MP-3D for precise indoor positioning and navigation, achieving an accuracy of ±2cm (about 0.79 in). By integrating multiple frequency options and IMU sensors, Marvel Mind enhances update rates and provides a versatile solution for autonomous indoor navigation of robots, surpassing the limitations of traditional ultra-wideband and BLE systems. We did not choose this as our solution solely based on the cost of the product.

Xbox Kinect

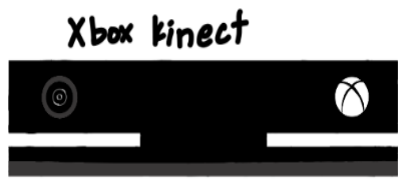
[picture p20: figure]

Technology that sends waves that bounce off objects and return to the transducer upon detection. Also utilizes features from an optical camera at the same time.

The Xbox Kinect is an RGB color VGA video camera that also utilizes a depth sensor that uses infrared light for 3D imagery. This device can detect movements and can map a room. Another useful function is that it has a microphone that can be used for voice commands. We could also use it to map out the table for the Romi bots and detect their movements. We did not choose this as our solution because it couldn't get the precision of 5mm (about 0.2 in) that our sponsor was looking for.

GPS | Technology that relies on satellite signals received by specialized receivers to triangulate an object's precise location. | GPS, or Global Positioning System, uses satellites to determine geolocation information. While commonly used, it lacks millimeter-precise tracking and indoor use can hamper the signal. The issue with GPS systems is that they would not give the exact location of the Romi bots on the table, GPS is good for giving general position.

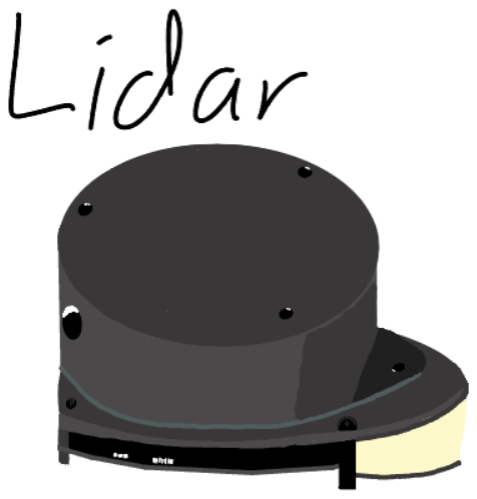
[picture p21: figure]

Lidar | Technology that employs laser pulses to measure distances by analyzing the reflection of light from objects. | This technology boasts high accuracy with a margin of ± 2mm. However, for large companies, the cost of 3D Lidar can exceed thousands of dollars. The limitation of Slamtec RPLIDAR A1 lies in its 2D scanning capability along a single plane.

## Appendices

## Preliminary analysis

In our concept prototype phase, our focus was on understanding the functionality of our solution. Utilizing a 3D printed housing and a tripod provided by one of our team members, we visualized the design of our solution as shown in Figure 3. Through this process, we recognized that employing a tripod design might necessitate the housing with sensors to pan back and forth to scan the entire table effectively as shown through Figure 4. The envisioned setup allows the camera to swing and cover the full length of the table, ensuring comprehensive scanning. Moreover, we acknowledged the significance of positioning our device appropriately.

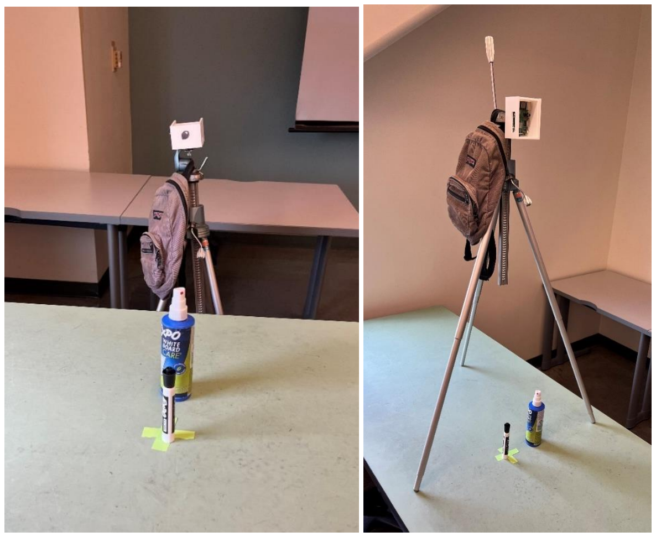
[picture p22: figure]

Figure 3. Demonstration of our housing overlooking a table from both a side view (left) and a top-down perspective (right), indicating potential limitations in object detection depending on their placements.

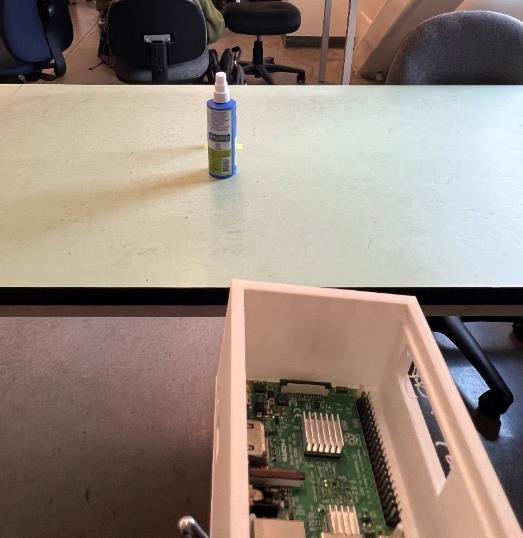
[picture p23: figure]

Figure 4. A demonstration of our housing overlooking the table from a side view. This view complements the insights gained from Figure 3, emphasizing the importance of device positioning for optimal scanning efficiency.

Also, if we continue using this specific tripod setup, we will have to consider seeing the legs on the table. We have also discussed possibly putting our housing higher vertically. For testing, we have been using a tripod, but our sponsor has given the okay to make this device ceiling-mounted or even wall-mounted. If we had the device ceiling mounted, then it would have a larger field of view and would no longer have to pan back and forth. To mount the device to the ceiling, what we would do is 3-D print a tile the size of one in the classroom to replace it. Since we would need to attach the device, we do not want to damage one of the tiles that is in the classroom. This would make it easier to get approval to have the device installed on the ceiling. Figure 5 showcases the second iteration of our housing.

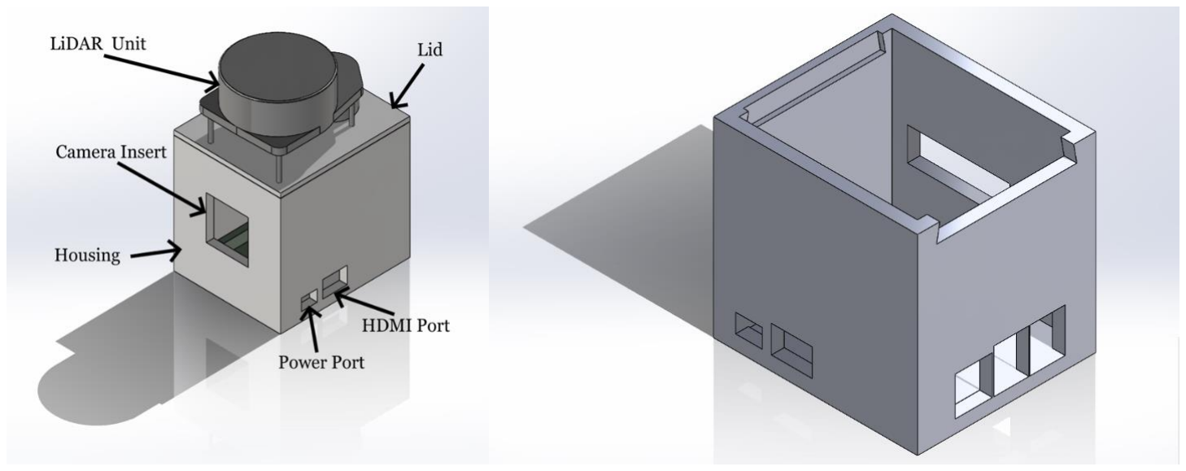
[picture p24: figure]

Figure 5. This is the second iteration of housing incorporating improvements based on insights gained from the initial print.

From designing this first housing, we gained a lot of insight on what to address in the next iteration. One such oversight was the failure to account for a breadboard, which will be necessary for developing the prototype and getting the Raspberry Pi to interface with the sensor attached. This can be remedied by making the housing larger by adding a slot for the breadboard to slide into. Another issue with this iteration is that the ports were made too small and should be fixed by making them much larger to account for cable limitations and not port limits. Another insight gained was that we could have a cutout on the front of the housing (where the lens is drawn) to accommodate a Raspberry Pi camera. As printing and iteration continue, we will continue to refine our solution based on the feedback we hear as well as adapting to any issues that may arise in the foreseeable future.

Following a meeting with our sponsor, it was brought to our attention that the previous SLAMTEC A1 LiDAR sensor is only capable of scanning in a 2D plane, which would mean that the sensor would have to be mounted on each individual Romi. This would not only not be able to obtain absolute positioning data but also vastly exceed budget. In lieu of LiDAR sensors, we will be focusing on a camera-based tracking solution, where the Romi robots will be tracked using image processing. Our project direction will be shifted to configuring our housing towards
the Adafruit Raspberry Pi High-Quality Camera.

Initial analysis into using the camera as the tracking sensor seems favorable. In an ideal scenario where the camera is mounted to the roof and is perfectly centered over the table, we can calculate the viewing area from camera’s field of view and mounting distance. Such a setup is depicted in Figure 6 below.


Figure 6. A 3D sketch of the camera set up above the table and its viewing area, and a 2D representation of the viewing area of the camera.

The viewing area of the camera can be thought of as a rectangle of sides DHor and DVert for horizontal and vertical distances respectively. We can find each side by taking a triangle of base (D) and height (H) with angle Field of View (FOV). We are given HMount, which is the distance of the camera above the table and FOV, which is given by the camera lens used. For example, let’s solve for the horizontal distance DHor. We can break this down into a right triangle as shown in Figure 7 below.


Figure 7. 2D View Triangle

Using trigonometry, we obtain

tan (

HFOV
2

) =

(DHor/2)

(Hmount)

Rearranging the equation,

DHor = 2Hmount tan (

HFOV
2

)

Solving for the vertical distance DVert follows a similar process, so similar equation can be used.

DVert = 2Hmount tan (

VFOV
2

)

Using these two distances, we can calculate the viewing area of the camera.

AView = DHor ∗ DVert

Finally, by dividing viewing area by the pixel count, we can determine the area of each pixel in the image, which will be our tracking resolution area.

Apix =

AView
# ofPixels

A pixel is a square, so using the area of the pixel, we can determine the pixel width, which will be our tracking resolution.

Wpix = √Apix

# Idea List

Here is a full list of all ideas generated during our ideation phase.

- Swarm Intelligence optimization
- SLAM- Simultaneous Localization and mapping algorithms
- Topology-aware IMU fusion
- Collaborative Sensor fusion
- Dynamic Bayesian Network (DBN) Localizations
- Uses IMU data w/ other sensor inputs to probabilistically estimate their loc.
- Acoustic Localization
- Reflective markers & Photodetectors
- IMU-based dead reckoning
- IMU w/ Bluetooth
- Ultrasonic sensors w/ IMU
- Sony Mocopi IMU
- Haritora Wireless IMU
- TAG Romi
- Force Romi
- HTC Vive trackers, SteamVR base stations (LiDAR)
- LiDAR (light detection & ranging)
- Computer vision of markers
- Wi-Fi Positioning system
- Bluetooth Beacons
- GPS w/ Bluetooth
- GPS module
- IR w/ IMU
- Infrared beacon tracking
- Neural-link Romi
- Romi Bar
- Train Romi
- Line-following Romi
- Augmented Reality (Pokémon GO style)
- Facial recognition tracking
- Camera (regular)
- Puck-based location
- Magnetic encoders
- Magnetic field sensors
- RFID (relative location to known reference points)
- Ping system (Like Skylanders RFID tags)
- Romi piloted by Xbox Controller (Sub Style)
- Computer Mouse-style tracking
- Xbox Kinect (motion detection)
- Xbox Kinect w/ IMU

- Disney Trackless systems
- Some guy shouting coordinates
- String-pulley positioning
- Laser Range Finders – w/ IMU
- Laser Pointer
- Coordinate Streaming Bluetooth
- Coordinate Streaming Ethernet cables
- Wi-Fi location?
- Scent beacons
- Star charts
- Coordinate Streaming Wi-fi
- Fire Tracking
- Temperature Tracking
- Thermal Tracking (NVG)
- Romi-Romi peer to peer coordinate streaming
- Twitch Stream Tracking
- Amazon Warehouse Robots

# Weighted Design Matrix


# Up to date Gantt Chart


# Design Hazard Matrix

Y | N
| N | 1. Will any part of the design create hazardous revolving, reciprocating, running, shearing, punching, pressing, squeezing, drawing, cutting, rolling, mixing or similar action, including pinch points and sheer points?
| N | 2. Can any part of the design undergo high acceleration/deceleration?
| N | 3. Will the system have any large moving masses or large forces?
| N | 4. Will the system produce a projectile?
Y | | 5. Would it be possible for the system to fall under gravity creating injury?
| N | 6. Will a user be exposed to overhanging weights as part of the design?
| N | 7. Will the system have any sharp edges?
| N | 8. Will any part of the electrical systems not be grounded?
Y | | 9. Will there be any large batteries or electrical voltage in the system above 40 V?
| N | 10. Will there be any stored energy in the system such as batteries, flywheels, hanging weights or pressurized fluids?
| N | 11. Will there be any explosive or flammable liquids, gases, or dust fuel as part of the system?
| N | 12. Will the user of the design be required to exert any abnormal effort or physical posture during the use of the design?
| N | 13. Will there be any materials known to be hazardous to humans involved in either the design or the manufacturing of the design?
| N | 14. Can the system generate high levels of noise?
| N | 15. Will the device/system be exposed to extreme environmental conditions such as fog, humidity, cold, high temperatures, etc?
| N | 16. Is it possible for the system to be used in an unsafe manner?
| N | 17. Will there be any other potential hazards not listed above? If yes, please explain on reverse.

Description of Hazard | Planned Corrective Action | Planned Date | Actual Date
Possibility of the system falling from gravity. | During testing, we'll exclusively use a tripod. For the final product, we'll employ secure and non-destructive ceiling mounting to minimize instability and prevent falls.
The system will be plugged into a wall outlet. | Caution will be taken when plugging or unplugging the system from the wall outlet. No sharp or hot objects should be left near any wires or components.

# References

[1] M. Eisoldt et al., “A fully integrated system for hardware-accelerated TSDF SLAM with LiDAR sensors (HATSDF SLAM),” Robotics and Autonomous Systems, vol. 156, p. 104205, Oct. 2022, doi: https://doi.org/10.1016/j.robot.2022.104205.

HATSDF SLAM, an energy-efficient TSDF SLAM implementation for mobile robots, achieves real-time performance with 18 times lower energy requirements per frame than a state-of-the-art PC by leveraging embedded ARM processors and FPGA-based hardware accelerators. Its integrated ROS bridge enables online mapping inspection and offline evaluation of datasets, demonstrating accurate pose estimation with minimal drift in various scenarios compared to established SLAM algorithms. Future developments aim to implement runtime hardware reconfiguration for automatic adaptation to changing environmental conditions, enhance TSDF volume resolution, and reduce registration time for high-resolution LiDAR data using memory-efficient data structures and potentially incorporating feature-based SLAM methods.

[2] A. Geiger, P. Lenz, C. Stiller, and R. Urtasun, “Vision meets robotics: The KITTI dataset,” The International Journal of Robotics Research, vol. 32, no. 11, pp. 1231–1237, Aug. 2013, doi: https://doi.org/10.1177/0278364913491297.
The article introduces the KITTI dataset, a comprehensive resource for research in mobile robotics and autonomous driving, captured from a VW station wagon. Noteworthy aspects include 6 hours of diverse, calibrated, and synchronized traffic scenarios recorded with a range of sensors. The dataset provides 3D object labels and benchmarks, contributing significantly to the development and evaluation of computer vision and robotic algorithms for autonomous driving.
[3] T. T. Do and H. Ahn, “Visual-GPS combined ‘follow-me’ tracking for selfie drones.” Advanced Robotics, vol. 32, no. 19, pp. 1047-1060, 2018, doi: https://doi.org/10.1080/01691864.2018.1501278.

The paper proposes a hybrid approach for the 'follow-me' mode in camera drones, specifically selfie drones, aiming to improve targeting accuracy. Current commercial drones rely on GPS data for tracking, but this can lead to unsatisfactory results due to GPS inaccuracies. The proposed approach combines the short-term accuracy of a visual tracking algorithm with the long-term reliability of GPS-based tracking, demonstrating superior accuracy in follow-me operations compared to GPS-based methods. The system also exhibits quick recovery from visual tracking failures and Wi-Fi disruptions in short-term scenarios.

[4] E. Bostanci, B. Bostanci, N. Kanwal, and A. F. Clark, “Sensor fusion of camera, GPS and IMU using fuzzy adaptive multiple motion models,” Soft Computing, vol. 22, no. 8, pp. 2619–2632, Feb. 2017, doi: https://doi.org/10.1007/s00500-017-2516-8.

The paper addresses the challenges in user tracking for augmented reality (AR) applications, emphasizing the importance of accuracy and frame rate. It explores a fusion approach, combining vision-based estimates with GPS and IMU measurements to enhance tracking accuracy in outdoor environments. The use of Fuzzy Adaptive Multiple Models, a novel fuzzy rule-based approach, is investigated to improve accuracy and convergence speed in the fusion filter. The results demonstrate the developed tracking system's superior accuracy compared to conventional GPS–IMU fusion approaches, with applications highlighted in cultural heritage contexts.

[5] L. Veronese, F. AuatźCheein, T. Bastos, A. FerreiraźDeźSouza, and Edilson de Aguiar, “A Computational Geometry Approach for Localization and Tracking in GPS-denied Environments*,” Journal of Field Robotics, vol. 33, no. 7, pp. 946–966, Jul. 2015, doi: https://doi.org/10.1002/rob.21594.

The paper proposes a hybrid approach for the 'follow-me' mode in camera drones, specifically selfie drones, aiming to improve targeting accuracy. Current commercial drones rely on GPS data for tracking, but this can lead to unsatisfactory results due to GPS inaccuracies. The proposed approach combines the short-term accuracy of a visual tracking algorithm with the long-term reliability of GPS-based tracking, demonstrating superior accuracy in follow-me operations compared to GPS-based methods. The system also exhibits quick recovery from visual tracking failures and Wi-Fi disruptions in short-term scenarios.

[6] A.-T. Popovici, C.-C. Dosoftei, and C. Budaciu, “Kinematics Calibration and Validation Approach Using Indoor Positioning System for an Omnidirectional Mobile
Robot.” Sensors, vol. 22, no. 22, p. 8590, 2022, doi: 10.3390/s22228590.

The paper proposes an extended calibration approach to enhance the motion response of Omnidirectional Mobile Robots (OMRs) in indoor environments, specifically addressing mechanical imperfections such as misalignment. Utilizing an Indoor Positioning System ( IPS) based on ultrasound technology, the study demonstrates significant reductions in motion errors, particularly in rotation correction factors. The research contributes to the advancement of precise and reliable navigation for autonomous mobile robots, crucial for applications in coordination and warehouse management.

[7] Zhu, Yu, and Xiao, “An Unconventional Multiple Low-Cost IMU and GPS-Integrated Kinematic Positioning and Navigation Method Based on Singer Model,” Sensors, vol. 19, no. 19, p. 4274, Oct. 2019, doi: https://doi.org/10.3390/s19194274.

The paper introduces an unconventional multiple low-cost Inertial Measurement Unit (IMU) and GPS-integrated kinematic positioning and navigation method based on the Singer acceleration model. The individual modeling method, a key component of this approach, dynamically adjusts systematic error estimations for each IMU in real-time, offering a more accurate representation of the actual situation. Despite the success of the proposed algorithm, the study highlights challenges related to the high computation load caused by frequent measurement updates in the Kalman filter, especially with IMUs operating at a high rate of 100 Hz. The paper concludes by suggesting future work on developing a more precise fusion algorithm using carrier phase information from the GPS.

[8] A. Saha, B. C. Dhara, S. Umer, K. Yurii, J. M. Alanazi, and A. A. AlZubi, “Efficient Obstacle Detection and Tracking Using RGB-D Sensor Data in Dynamic Environments for Robotic Applications,” Sensors, vol. 22, no. 17, p. 6537, Aug. 2022, doi: https://doi.org/10.3390/s22176537.

The paper proposes an efficient obstacle detection and tracking method using depth images, specifically with RGB-D camera sensors, for autonomous navigation in dynamic and cluttered environments. The approach employs a u-depth map for obstacle detection, with dynamic thresholding to enhance accuracy. Additionally, a restricted v-depth map technique is introduced for improved prediction of obstacle dimensions, and a novel algorithm facilitates obstacle tracking within the field of view. The system's performance is evaluated on various datasets, demonstrating its superiority over vision-based state-ofthe-art methods in terms of state estimation of dynamic obstacles and execution time.

[9] Z. Liu, F. Zhang, and X. Hong, “Low-cost Retina-like Robotic Lidars Based on Incommensurable Scanning,” IEEE/ASME Transactions on Mechatronics, pp. 1–1, 2021, doi: https://doi.org/10.1109/tmech.2021.3058173.

The paper introduces a novel lidar sensor designed for mass production in autonomous robots, utilizing incommensurable scanning for straightforward manufacturing. Inspired by the human retina's fovea, the lidar exhibits a peaked central angular density, making it well-suited for applications requiring eye-like attention. Its unique design allows for higher resolution than conventional lidars, with demonstrated advantages in sensor calibration and potential upgradability, providing a promising solution for the development of cost-effective and efficient autonomous robots.

[10] T. Zhe, L. Huang, Q. Wu, J. Zhang, C. Pei, and L. Li, “Inter-Vehicle Distance Estimation Method Based on Monocular Vision Using 3D Detection.” IEEE Transactions on Vehicular Technology, vol. 69, no. 5, pp. 4907-4919, 2020, doi: https://doi.org/10.1109/TVT.2020.2977623

The paper addresses challenges in autonomous vehicle perception systems, focusing on cost-effective solutions using monocular vision for inter-vehicle distance estimation. While traditional systems rely on expensive sensors, the proposed driving assistance system (DAS) leverages monocular vision-based methods. The study introduces a novel approach, combining 3D detection and an area-distance geometric model to enhance accuracy and robustness in inter-vehicle distance estimation. The method demonstrates superior performance in complex traffic scenarios, outperforming existing methods, with an accuracy deviation below 2% for vehicles with different visual angles.

[11] YoungWonks, “An introduction to magnetometers, where they are used and how they work,” YoungWonks. https://www.youngwonks.com/blog/What-is-a-Magnetometer-and-How-Does-It-Work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 (https://www.youngwonks.com/blog/What-is-a-Magnetometer-and-How-Does-It-Work)

This article provides an overview of magnetometers, describing their function, working principles, applications, calibration methods, and types. It offers a detailed exploration of magnetometers, devices crucial for measuring magnetic fields’ strength and orientation. It elucidates their devices working principles, including the Hall effect, magnetoinduction, and magnetoresistance, each method discerning changes in current or resistance when exposed to magnetic fields.

[12] “What is Lidar? Learn How Lidar Works,” Velodyne Lidar. https://velodynelidar.com/what-is-lidar/#:~:text=and%20weather%20conditions.-

The article introduces lidar (light detection and ranging), highlighting its use of eye-safe laser beams to generate a 3D representation of the environment. It explains the working principle of lidar: the sensor emits pulsed light waves, which bounce off objects and return to the sensor. By calculating the time taken for each pulse to return, the sensor determines the distance traveled, creating a real-time 3D map known as a point cloud. Overall, the article provides a clear and concise overview of lidar’s functionality and applications.

[13] “How It Works: Xbox Kinect,” Jameco.com, 2019. https://www.jameco.com/jameco/workshop/howitworks/xboxkinect.html

This article delves into the inner workings of the Xbox Kinect, a revolutionary gaming device eliminating the need for a traditional controller and enabling full-body interaction within games. It describes the Kinect’s intricate software and hardware components. The software leverages extensive motion-capture data and utilizes artificial intelligence and machine learning algorithms to interpret real-life movements and map them onto virtual avatars. The hardware consists of an RGB color VGA video camera, a depth sensor, and a multi-array microphone, which collectively track various points on the player’s body. Overall, the article provides a comprehensive overview of the Xbox Kinects technology.

[14] “Apple AirTags: Everything You Need to Know” PCMag. https://www.pcmag.com/howto/apple-airtag-tips (https://www.pcmag.com/how-to/apple-airtag-tips)
Apple AirTags are compact trackers designed to help users locate misplaced or stolen items using the Find My app. Priced at $29 each or $99 for a pack of four, AirTags use ultra-wideband technology and Apple's device network for precise location tracking. Setup is straightforward, requiring a compatible iPhone or iPad running iOS 14.5 or above. The device boasts a one-year battery life and uses standard CR2032 batteries. Security measures include end-to-end encryption, alerts for unwanted tracking, and NFC functionality for Android users to connect to lost AirTags. The product provides a blend

of precision, security, and privacy for tracking personal belongings.

[15] “Starter Set Super-MP-3D” Marvelmind robotics. https://marvelmind.com/product/starterset-super-mp-3d/ (https://marvelmind.com/product/starter-set-super-mp-3d/)

The Starter Set Super-MP-3D is a cutting-edge indoor positioning and navigation system designed for precise tracking in industrial settings. With ±2cm accuracy, it is ideal for automation, safety, and productivity applications. The versatile set supports multiple configurations, including 1D, 2D, and 3D, and offers Multi-Frequency support for increased update rates. Utilizing Super-Beacon technology with 6D IMU, the system provides superior performance compared to previous versions. It operates in license-free radio bands and includes advanced features such as ultrasound frequency selection and sharp DSP filters. The set is easy to deploy, with no manual calibration required, making it a comprehensive solution for indoor tracking of robots, vehicles, and drones.

[16] Teleoperator system with master controller device and multiple remote slave devices, by William T. Townsend. (2011, Aug 11.). US20120041599A1. [Online]. Available: https://patents.google.com/patent/US20120041599A1/en?oq=US20120041599A1

This patent describes using a master system to control multiple connected robots. The idea presented in this patent could be used as the GPS sensor developing could be the master system that streams data in cartesian space to its subordinate devices. We learned that multiple robots can be controlled from a master device rather than on-board hardware.

[17] Magnetic vector sensor positioning and communication system, by Larry W. Fullerton. (2016, Mar 24.). US9566599B2. [Online] Available: https://patents.google.com/patent/US9588599B2/en?oq=US9588599

This patent describes a magnetic vector positioning system that uses magnetic vector sensors to determine position or to transmit data. This has potential use of determining Romi orientation and position using magnetometers. We learned that magnetometers can also be used to transmit data and locate an object.

[18] Celestial navigation system for an autonomous robot, by Mark Joseph Chiappetta. (2005, Jul. 7). US7706917B1. [Online] Available: https://patents.google.com/patent/US7706917B1/en?oq=US7706917

This patent describes an onboard celestial navigation system for indoor robots. This could be used as a basis for mounting an external tracking system or an alternate way to obtain navigation data on board the Romis. We learned that a series of multiple beacons can be used for orientation and location data through relativity.

[19] Video image-based control system by Francis MacDougall. (1991, May 11.) US5534917A. [Online] Available: https://patents.google.com/patent/US5534917A/en?oq=US5534917

This patent describes a video-based tracking system where a video is converted to data to control a device. This can be used as a low-cost way to track multiple robots simultaneously. We learned that to process video, a computer performs and functions on a bitmap to determine whether an object is in an area of interest.

[20] Indoor robot positioning method integrating visual odometer and physical odometer, by 周唐恺. (2017, Jun 2.). CN107356252B. [Online] Available: https://patents.google.com/patent/CN107356252B/en?oq=CN107356252B

This patent illustrates a tracking method by way of using visual and on-board odometers to determine the location of a robot. This may be a more accurate way of tracking compared to solely digital tracking and it complements Romi’s native odometer tracking. We learned that we could combine multiple existing solutions to improve location accuracy.

[21] Distributed localization systems and methods and self-localizing apparatus, by Marcus Hehn. (2016, Mar 7.). US20160259032A1. [Online] Available: https://patents.google.com/patent/US20160259032A1/en?oq=US20160259032A1

This patent describes using transceivers as a localization network that a device could use to determine its position relative to. This could be used as a solution where the robots would use the transceivers to compute its relative location on-board.

[22] Image-based georeferencing, by James M. Janky. (2009, Sep 14.). US20110064312A1. [Online] Available:
https://patents.google.com/patent/US20110064312A1/en?oq=US20110064312A1

This patent describes an image-based system, which georeferenced features based on the difference between two pictures. This could be implemented by comparing a picture feed with Romi robots versus a reference picture with no robots.

[23] Triangular interferometric light-source tracker, by Brett Alan Bordyn. (1974, Jul 26.). US4003658. [Online] Available: https://patents.google.com/patent/US4003658A/en?oq=US4003658

This patent describes a system that tracks a light source using orthogonal triangular interferometric systems on a gimbaled platform. This can be used to track the position of a Romi by attaching a light source to the robot, though the mechanisms required are complex.

[24] Autonomous coverage robot navigation system, by Daniel N. Ozick (2008, Dec 23.). US8380350. [Online] Available: https://patents.google.com/patent/CN107356252B/en?oq=CN107356252B

This patent describes an autonomous robot that uses aa base station with three infrared emitters to guide the robot. This could be used by the Romi robots to determine their position based on their location from the emitter.

[25] Vision based location estimation system by . (2017, Jun 2.). CN107356252B. [Online] Available: https://patents.google.com/patent/CN107356252B/en?oq=CN107356252B

This patent describes using multiple Kalman filters to process data from an ultra-wideband positioning system, pressure sensors, temperature sensors, and inertial measurement data, to obtain precise location data. This process could be used to combine several onboard sensors already implemented on the Romi with the prototype to further increase the precision of positional data.

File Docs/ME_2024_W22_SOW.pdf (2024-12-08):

# Pseudo GPS for Romi

January 18, 2024

For Charlie Refvem

Team

Emmanuel Baez – embaez@calpoly.edu

Gabriel Coria – gacoria@calpoly.edu

Owen Guinane – oguinane@calpoly.edu

Conor Schott – cjschott@calpoly.edu

College of Engineering

California Polytechnic State University, San Luis Obispo

2024

## Statement of Disclaimer

Since this project is a result of a class assignment, it has been graded and accepted as a fulfillment of the course requirements. Acceptance does not imply technical accuracy or reliability. Any use of information in this report is at risk to the user. These risks may include catastrophic failure of the device or infringement of patent or copyright laws. California Polytechnic State University at San Luis Obispo and its staff cannot be held liable for any use or misuse of the project.

## Table of Contents

## Four Panel Chart

Project Overview

- Project Objective: Currently, the Romi robots used in the Mechatronics lab have no way of obtaining absolute orientation or location from onboard sensors. The Cal Poly ME 405 instructor, Charlie Refvem, and Mechatronics students need a way to deliver precise and real-time location data for multiple Romi robots for the development of better algorithms. Our aim is not just to improve tracking but also to enhance communication standards among multiple Romis by ensuring geolocation accuracy, precision, range, latency, and update rates.
- GPS Prototype Goals: Provide precise, real-time location data for multiple mobile robots, improving tracking and communication standards.
- Team Structure: Sponsored by Mechatronics professor Charlie Refvem, the team comprises Emmanual Baez (Communications Lead), Gabriel Coria (Treasurer), Owen Guinane (Secretary), and Conor Schott (Planner).
- Documentation and Impact: The project involves comprehensive documentation, including detailed electrical schematics and code explanations.

Key Specifications

- The code can be run on C, C++, and Python for the external device. The Romi must be coded on uPython while running on a Nucleo
- There should be a microcontroller used to control the external device
- The Robots that will be used are Pololu Robotics Romi Chassis
- The group must be able to provide a wiring diagram of all components connected
- The code must be well-documented
- The solution’s initial budget is $500 but can be increased with Charlie’s approval
- The device attached to the Romi should be small and lightweight, whereas the external device should also be lightweight but have more freedom on size
- Looking for a system capable of emitting at 5 Hz for a group of six to ten robots
- The accuracy for positional data must be within 5 mm (about 0.2 in)

Scope And Deliverables

We will be creating a proof of concept for a system to monitor Romis in real-time along with extensive coding and hardware documentation. The scope of this project encompasses the design, development, and testing phases, with the primary focus on creating a versatile and efficient GPS.

What’s Next

We will explore our ideation models, polish our Statement of Work (SOW), develop our Preliminary Design Review (PDR), and explore the possibility of testing specific sensors at Charlie's discretion.

## Problem Statement

Currently, the Romi robots used in the Mechatronics lab use IMUs to get absolute orientation data but have no way of obtaining locational data from any other onboard sensors. The Cal Poly ME 405 instructor, Charlie Refvem, and Mechatronics students need a way to deliver precise and real-time location data for multiple Romi robots for the development of better algorithms. Our aim is not just to improve tracking but also to enhance communication standards among multiple Romis by ensuring geolocation accuracy, precision, range, latency, and update rates.

## Overview

This report aims to document our design process as we work to develop a solution to provide a pseudo-GPS system for the robots in the Mechatronics lab. In it, we will establish a background of the project and the results of our research, a scope where we will determine the needs and deliverables of the project, an objectives section that fully defines our problem and design specifications, and a Project Management plan that will explain the process that we will follow going forward.

By the Fall quarter of 2024, we will deliver detailed documentation, including electrical schematics and a written explanation of the code and its functions.

Our group is tasked with providing analysis, testing results, and characteristics of the prototyped sensor, evaluating aspects such as accuracy, precision, range, update rate, and latency. Several existing solutions share similarities with our project. Among these devices are equipped with built-in GPS systems, enabling users to track them via smartphones. Examples include Marvel Mind, the Apple Air tag, the Goodly mini-GPS tracker, and the LandAirSea 54 real-time GPS tracker. While these devices are pricier and come pre-coded for immediate use, unlike our project, studying their functionalities can provide valuable insights for our development. Additionally, there are advanced cameras capable of tracking selected objects, such as indoor positioning systems, the Lumens VC-TR1 auto-tracking PTZ camera, and the Yealink UVC86 4K dual-lens speaker tracking camera. Another option we explored was body-tracking technology, which led us to the Xbox Kinect, renowned for its body-tracking capabilities. This emerged as one of our top choices for tracking Romis. Although certain technologies, like Roombas, infrared sensors, garage door sensors, wireless driveway alarms, and satellites, are beyond our budget constraints, researching their functionalities allows us to integrate innovative ideas into our project.


Figure 1: Boundary Sketch

## Customer Needs

Table 1: Customer Needs

Customer Needs | Relevant Engineering Specs | Justification
Attachments need to fit on the Romi Robot. | Our geometry should fit on a Romi that is 6.4in x 5.8in x 2.75in | Since we are using a Romi, we need to be able to fit the device on one.
The system needs to track the table's length and width in the Mechatronics lab. | Our table’s base should be 46in x 96in. | The customer wants to perform laboratory tests on these lab tables.
The system needs to be powered by an external or internal source. | Devices on Romi must run at either 3.3V,5V, or 7.2V. External parts can be powered from a wall outlet. | Tracking sensors will take power in the form of batteries or a charging outlet. It also requires quick upload and download of data to process.
The system needs to have a good update rate for data transfer. | Our update rate should be 6Hz or more. | Our sponsor suggests an update rate of about 6Hz.
The system should be able to track multiple Romi bots at a time. | The device should be able to track up to six Romis. | Our sponsor has multiple Romis that the students use in the lab.
The system should be easy to take apart and moveable if it is not mounted. | Must be mounted in a non-destructive way when placed on the ceiling. Needs an elevated structure to replace the main component on the ceiling. The main component should also have protected housing against slight vibration and magnets. | Since the assembly will be constantly moving, we do not want there to be significant vibrations between components. Furthermore, we want our sensors to be protected from magnets.
The system should be within budget to produce. | The manufacturing cost should be around $500 but more money can be spent if approved by the sponsor. | Since we will not build our microcontroller and sensor, we will use our funds to buy components from manufacturers.

Table 1 shows the customer needs and the engineering specifications that our group needs to follow. We also added a justification for why the engineering specifications were chosen.

## Engineering Specifications

Table 2: Engineering Specifications

Spec # | Specification Title | Specification Description | Target (units) | Tolerance | Risk * | Compliance **
1 | Total System Length | The system would prefer to be able to fit onto a Romi. | Romi Size | ±0.010 in. | L | A, I
2 | Total System Weight | The Romi will also have other sensors attached to it, so we would not want to encumber it further. | 2 lbs. | Max | L | A, I
3 | Field of View | The system should track a Romi placed on the classroom table. | 96x48 in. | Max | H | A, I
4 | Max Power Capability | The system should be powered by a wall outlet. Technology on Romi should be powered by a battery. | 7.2 V | Max | L | I, T
5 | Data Transfer | The system should be able to transfer data at a high rate. | 6 Hz | Min | M | A, T
6 | Number of Romis being detected | The system should be able to track multiple Romis | 6 | Min | L | A, T
7 | Tracking Resolution | The system should be able to track the position of Romi. | 5 mm positioning | Max | H | A, I
8 | Production Cost | The budget is $500. (could be higher) | $500 | Max | M | A
8 | Housing | The system needs to house the microcontroller we will be using as well as the sensors we will be using for detection and data transfer Some type of easy access to the batteries or charging port. | 85 L X 56 W X 19 H mm | Min | L | I, T

Needs to be easy to
move if needed.

* Risk of meeting specification: (H) High, (M) Medium, (L) Low
** Compliance Methods: (A) Analysis, (I) Inspection, (S) Similar to Existing, (T) Test

This table outlines the project’s essential specifications, categorized based on their priority and corresponding compliance methods. Each specification is accompanied by detailed information and our target goal for reference.

## Existing Solutions

Table 3: Existing Solutions

Solution Type | Description | Examples
GPS Systems | Technology that relies on satellite signals received by specialized receivers to triangulate the object's precise location. Therefore, it can be used for mapping, route planning, and real-time positional monitoring. | Marvel Mind utilizes GPS technology in their Starter Set Super-MP-3D for precise indoor positioning and navigation, achieving an impressive accuracy of ±2cm. By integrating multiple frequency options and IMU sensors, Marvel Mind enhances update rates and provides a versatile solution for autonomous indoor navigation of robots, surpassing the limitations of traditional ultra-wideband and BLE systems [15],[3].
Lidar Technology | Lidar is a technology that sends out a laser to a targeted object and measures the time it takes to return to the receiver to get the range. | Steam VR Base stations and HTC Vive Trackers are used by people in Virtual Reality to track the location of their full body in games [1], [9], [12].
Motion Detection | Technology that sends out sound waves at frequencies above the range of hearing. The sound waves bounce back off the objects and come back to the transducer which sends and receives the sound waves when an object comes in front of the detecting area. | The Xbox Kinect, a device that adds motion controls to Xbox game consoles, can be used to track objects in space using its variety of sensors [13].
Infrared Technology | Technology that emits and receives infrared radiation, bounces off objects and goes back to the receiver. This technology can tell how far objects are as well as detect motion. | Roomba Vacuums use infrared stations to help navigate back to their charging ports [24].
Beacons | This technology emits a signal that a device can use to determine its location based on its distance from the source. | Magnetometers use the strength of a magnetic field to determine its relative position [12]. Apple Air tags use a Bluetooth signal to

| | determine how far away an iPhone is from it [14].
Optical Technology | This technology uses light signals to transmit data through optical fibers. Camera lenses take light rays that bounce around and use a glass to redirect them to a single point to take a picture. | Cameras can be used to take a video of the field which can then be processed by a computer to determine an object’s location. [4], [7].

This table presents diverse solution options for our group to explore and research. While there are various possibilities, the challenge lies in narrowing down choices based on feasibility and compatibility with our technology. Each solution is accompanied by a brief description of its working, along with examples of products that have successfully implemented them.

## Annotated Bibliography

## Relevant Articles

[1] M. Eisoldt et al., “A fully integrated system for hardware-accelerated TSDF SLAM with LiDAR sensors (HATSDF SLAM),” Robotics and Autonomous Systems, vol. 156, p. 104205, Oct. 2022, doi: https://doi.org/10.1016/j.robot.2022.104205.

HATSDF SLAM, an energy-efficient TSDF SLAM implementation for mobile robots, achieves real-time performance with 18 times lower energy requirements per frame than a state-of-the-art PC by leveraging embedded ARM processors and FPGA-based hardware accelerators. Its integrated ROS bridge enables online mapping inspection and offline evaluation of datasets, demonstrating accurate pose estimation with minimal drift in various scenarios compared to established SLAM algorithms. Future developments aim to implement runtime hardware reconfiguration for automatic adaptation to changing environmental conditions, enhance TSDF volume resolution, and reduce registration time for high-resolution LiDAR data using memory-efficient data structures and potentially incorporating feature-based SLAM methods.

[2] A. Geiger, P. Lenz, C. Stiller, and R. Urtasun, “Vision meets robotics: The KITTI dataset,” The International Journal of Robotics Research, vol. 32, no. 11, pp. 1231–1237, Aug. 2013, doi: https://doi.org/10.1177/0278364913491297.
The article introduces the KITTI dataset, a comprehensive resource for research in mobile robotics and autonomous driving, captured from a VW station wagon. Noteworthy aspects include 6 hours of diverse, calibrated, and synchronized traffic scenarios recorded with a range of sensors. The dataset provides 3D object labels and benchmarks, contributing significantly to the development and evaluation of computer vision and robotic algorithms for autonomous driving.
[3] T. T. Do and H. Ahn, “Visual-GPS combined ‘follow-me’ tracking for selfie drones.” Advanced Robotics, vol. 32, no. 19, pp. 1047-1060, 2018, doi: https://doi.org/10.1080/01691864.2018.1501278.

The paper proposes a hybrid approach for the 'follow-me' mode in camera drones, specifically selfie drones, aiming to improve targeting accuracy. Current commercial drones rely on GPS data for tracking, but this can lead to unsatisfactory results due to GPS inaccuracies. The proposed approach combines the short-term accuracy of a visual tracking algorithm with the long-term reliability of GPS-based tracking, demonstrating superior accuracy in follow-me operations compared to GPS-based methods. The system also exhibits quick recovery from visual tracking failures and Wi-Fi disruptions in short-term scenarios.

[4] E. Bostanci, B. Bostanci, N. Kanwal, and A. F. Clark, “Sensor fusion of camera, GPS and IMU using fuzzy adaptive multiple motion models,” Soft Computing, vol. 22, no. 8, pp. 2619–2632, Feb. 2017, doi: https://doi.org/10.1007/s00500-017-2516-8.

The paper addresses the challenges in user tracking for augmented reality (AR) applications, emphasizing the importance of accuracy and frame rate. It explores a fusion approach, combining vision-based estimates with GPS and IMU measurements to enhance tracking accuracy in outdoor environments. The use of Fuzzy Adaptive Multiple Models, a novel fuzzy rule-based approach, is investigated to improve accuracy and convergence speed in the fusion filter. The results demonstrate the developed tracking system's superior accuracy compared to conventional GPS–IMU fusion approaches, with applications highlighted in cultural heritage contexts.

[5] L. Veronese, F. AuatźCheein, T. Bastos, A. FerreiraźDeźSouza, and Edilson de Aguiar, “A Computational Geometry Approach for Localization and Tracking in GPS-denied Environments*,” Journal of Field Robotics, vol. 33, no. 7, pp. 946–966, Jul. 2015, doi: https://doi.org/10.1002/rob.21594.

The paper proposes a hybrid approach for the 'follow-me' mode in camera drones, specifically selfie drones, aiming to improve targeting accuracy. Current commercial drones rely on GPS data for tracking, but this can lead to unsatisfactory results due to GPS inaccuracies. The proposed approach combines the short-term accuracy of a visual tracking algorithm with the long-term reliability of GPS-based tracking, demonstrating superior accuracy in follow-me operations compared to GPS-based methods. The system also exhibits quick recovery from visual tracking failures and Wi-Fi disruptions in short-term scenarios.

[6] A.-T. Popovici, C.-C. Dosoftei, and C. Budaciu, “Kinematics Calibration and Validation Approach Using Indoor Positioning System for an Omnidirectional Mobile
Robot.” Sensors, vol. 22, no. 22, p. 8590, 2022, doi: 10.3390/s22228590.

The paper proposes an extended calibration approach to enhance the motion response of Omnidirectional Mobile Robots (OMRs) in indoor environments, specifically addressing mechanical imperfections such as misalignment. Utilizing an Indoor Positioning System ( IPS) based on ultrasound technology, the study demonstrates significant reductions in motion errors, particularly in rotation correction factors. The research contributes to the advancement of precise and reliable navigation for autonomous mobile robots, crucial for applications in coordination and warehouse management.

[7] Zhu, Yu, and Xiao, “An Unconventional Multiple Low-Cost IMU and GPS-Integrated Kinematic Positioning and Navigation Method Based on Singer Model,” Sensors, vol. 19, no. 19, p. 4274, Oct. 2019, doi: https://doi.org/10.3390/s19194274.

The paper introduces an unconventional multiple low-cost Inertial Measurement Unit (IMU) and GPS-integrated kinematic positioning and navigation method based on the Singer acceleration model. The individual modeling method, a key component of this approach, dynamically adjusts systematic error estimations for each IMU in real-time, offering a more accurate representation of the actual situation. Despite the success of the proposed algorithm, the study highlights challenges related to the high computation load caused by frequent measurement updates in the Kalman filter, especially with IMUs operating at a high rate of 100 Hz. The paper concludes by suggesting future work on developing a more precise fusion algorithm using carrier phase information from the GPS.

[8] A. Saha, B. C. Dhara, S. Umer, K. Yurii, J. M. Alanazi, and A. A. AlZubi, “Efficient Obstacle Detection and Tracking Using RGB-D Sensor Data in Dynamic Environments for Robotic Applications,” Sensors, vol. 22, no. 17, p. 6537, Aug. 2022, doi: https://doi.org/10.3390/s22176537.

The paper proposes an efficient obstacle detection and tracking method using depth images, specifically with RGB-D camera sensors, for autonomous navigation in dynamic and cluttered environments. The approach employs a u-depth map for obstacle detection, with dynamic thresholding to enhance accuracy. Additionally, a restricted v-depth map technique is introduced for improved prediction of obstacle dimensions, and a novel algorithm facilitates obstacle tracking within the field of view. The system's performance is evaluated on various datasets, demonstrating its superiority over vision-based state-of-the-art methods in terms of state estimation of dynamic obstacles and execution time.

[9] Z. Liu, F. Zhang, and X. Hong, “Low-cost Retina-like Robotic Lidars Based on Incommensurable Scanning,” IEEE/ASME Transactions on Mechatronics, pp. 1–1, 2021, doi: https://doi.org/10.1109/tmech.2021.3058173.

The paper introduces a novel lidar sensor designed for mass production in autonomous robots, utilizing incommensurable scanning for straightforward manufacturing. Inspired by the human retina's fovea, the lidar exhibits a peaked central angular density, making it well-suited for applications requiring eye-like attention. Its unique design allows for higher resolution than conventional lidars, with demonstrated advantages in sensor calibration and potential upgradability, providing a promising solution for the development of cost-effective and efficient autonomous robots.

[10] T. Zhe, L. Huang, Q. Wu, J. Zhang, C. Pei, and L. Li, “Inter-Vehicle Distance Estimation Method Based on Monocular Vision Using 3D Detection.” IEEE Transactions on

Vehicular Technology, vol. 69, no. 5, pp. 4907-4919, 2020, doi: https://doi.org/10.1109/TVT.2020.2977623

The paper addresses challenges in autonomous vehicle perception systems, focusing on cost-effective solutions using monocular vision for inter-vehicle distance estimation. While traditional systems rely on expensive sensors, the proposed driving assistance system (DAS) leverages monocular vision-based methods. The study introduces a novel approach, combining 3D detection and an area-distance geometric model to enhance accuracy and robustness in inter-vehicle distance estimation. The method demonstrates superior performance in complex traffic scenarios, outperforming existing methods, with an accuracy deviation below 2% for vehicles with different visual angles.

[11] YoungWonks, “An introduction to magnetometers, where they are used and how they work,” YoungWonks. https://www.youngwonks.com/blog/What-is-a-Magnetometer-and-How-Does-It-Work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 (https://www.youngwonks.com/blog/What-is-a-Magnetometer-and-How-Does-It-Work)

This article provides an overview of magnetometers, describing their function, working principles, applications, calibration methods, and types. It offers a detailed exploration of magnetometers, devices crucial for measuring magnetic fields’ strength and orientation. It elucidates their devices working principles, including the Hall effect, magneto-induction, and magnetoresistance, each method discerning changes in current or resistance when exposed to magnetic fields.

[12] “What is Lidar? Learn How Lidar Works,” Velodyne Lidar. https://velodynelidar.com/what-is-lidar/#:~:text=and%20weather%20conditions.-

The article introduces lidar (light detection and ranging), highlighting its use of eye-safe laser beams to generate a 3D representation of the environment. It explains the working principle of lidar: the sensor emits pulsed light waves, which bounce off objects and return to the sensor. By calculating the time taken for each pulse to return, the sensor determines the distance traveled, creating a real-time 3D map known as a point cloud. Overall, the article provides a clear and concise overview of lidar’s functionality and applications.

[13] “How It Works: Xbox Kinect,” Jameco.com, 2019. https://www.jameco.com/jameco/workshop/howitworks/xboxkinect.html

This article delves into the inner workings of the Xbox Kinect, a revolutionary gaming device eliminating the need for a traditional controller and enabling full-body interaction within games. It describes the Kinect’s intricate software and hardware components. The software leverages extensive motion-capture data and utilizes artificial intelligence and machine learning algorithms to interpret real-life movements and map them onto virtual avatars. The hardware consists of an RGB color VGA video camera, a depth sensor, and a multi-array microphone, which collectively track various points on the player’s body. Overall, the article provides a comprehensive overview of the Xbox Kinects technology.

[14] “Apple AirTags: Everything You Need to Know” PCMag. https://www.pcmag.com/how-to/apple-airtag-tips

Apple AirTags are compact trackers designed to help users locate misplaced or stolen items using the Find My app. Priced at $29 each or $99 for a pack of four, AirTags use ultra-wideband technology and Apple's device network for precise location tracking. Setup is straightforward, requiring a compatible iPhone or iPad running iOS 14.5 or above. The device boasts a one-year battery life and uses standard CR2032 batteries. Security measures include end-to-end encryption, alerts for unwanted tracking, and NFC functionality for Android users to connect to lost AirTags. The product provides a blend of precision, security, and privacy for tracking personal belongings.

[15] “Starter Set Super-MP-3D” Marvelmind robotics. https://marvelmind.com/product/starter-set-super-mp-3d/

The Starter Set Super-MP-3D is a cutting-edge indoor positioning and navigation system designed for precise tracking in industrial settings. With ±2cm accuracy, it is ideal for automation, safety, and productivity applications. The versatile set supports multiple configurations, including 1D, 2D, and 3D, and offers Multi-Frequency support for increased update rates. Utilizing Super-Beacon technology with 6D IMU, the system provides superior performance compared to previous versions. It operates in license-free radio bands and includes advanced features such as ultrasound frequency selection and sharp DSP filters. The set is easy to deploy, with no manual calibration required, making it a comprehensive solution for indoor tracking of robots, vehicles, and drones.

## Relevant Patents

[16] Teleoperator system with master controller device and multiple remote slave devices, by William T. Townsend. (2011, Aug 11.). US20120041599A1. [Online]. Available: https://patents.google.com/patent/US20120041599A1/en?oq=US20120041599A1
This patent describes using a master system to control multiple connected robots. The idea presented in this patent could be used as the GPS sensor developing could be the master system that streams data in cartesian space to its subordinate devices. We learned that multiple robots can be controlled from a master device rather than on-board hardware.
[17] Magnetic vector sensor positioning and communication system, by Larry W. Fullerton. (2016, Mar 24.). US9566599B2. [Online] Available: https://patents.google.com/patent/US9588599B2/en?oq=US9588599

This patent describes a magnetic vector positioning system that uses magnetic vector sensors to determine position or to transmit data. This has potential use of determining Romi orientation and position using magnetometers. We learned that magnetometers can also be used to transmit data and locate an object.

[18] Celestial navigation system for an autonomous robot, by Mark Joseph Chiappetta. (2005, Jul. 7). US7706917B1. [Online] Available: https://patents.google.com/patent/US7706917B1/en?oq=US7706917
This patent describes an onboard celestial navigation system for indoor robots. This could be used as a basis for mounting an external tracking system or an alternate way to obtain navigation data on board the Romis. We learned that a series of multiple beacons can be used for orientation and location data through relativity.
[19] Video image-based control system by Francis MacDougall. (1991, May 11.) US5534917A. [Online] Available: https://patents.google.com/patent/US5534917A/en?oq=US5534917

This patent describes a video-based tracking system where a video is converted to data to control a device. This can be used as a low-cost way to track multiple robots simultaneously. We learned that to process video, a computer performs and functions on a bitmap to determine whether an object is in an area of interest.

[20] Indoor robot positioning method integrating visual odometer and physical odometer, by 周唐恺. (2017, Jun 2.). CN107356252B. [Online] Available: https://patents.google.com/patent/CN107356252B/en?oq=CN107356252B

This patent illustrates a tracking method by way of using visual and on-board odometers to determine the location of a robot. This may be a more accurate way of tracking compared to solely digital tracking and it complements Romi’s native odometer tracking. We learned that we could combine multiple existing solutions to improve location accuracy.

[21] Distributed localization systems and methods and self-localizing apparatus, by Marcus Hehn. (2016, Mar 7.). US20160259032A1. [Online] Available: https://patents.google.com/patent/US20160259032A1/en?oq=US20160259032A1

This patent describes using transceivers as a localization network that a device could use to determine its position relative to. This could be used as a solution where the robots would use the transceivers to compute its relative location on-board.

[22] Image-based georeferencing, by James M. Janky. (2009, Sep 14.). US20110064312A1. [Online] Available:
https://patents.google.com/patent/US20110064312A1/en?oq=US20110064312A1
This patent describes an image-based system, which georeferenced features based on the difference between two pictures. This could be implemented by comparing a picture feed with Romi robots versus a reference picture with no robots.
[23] Triangular interferometric light-source tracker, by Brett Alan Bordyn. (1974, Jul 26.). US4003658. [Online] Available: https://patents.google.com/patent/US4003658A/en?oq=US4003658

This patent describes a system that tracks a light source using orthogonal triangular interferometric systems on a gimbaled platform. This can be used to track the position of a Romi by attaching a light source to the robot, though the mechanisms required are complex.

[24] Autonomous coverage robot navigation system, by Daniel N. Ozick (2008, Dec 23.). US8380350. [Online] Available: https://patents.google.com/patent/CN107356252B/en?oq=CN107356252B
This patent describes an autonomous robot that uses aa base station with three infrared emitters to guide the robot. This could be used by the Romi robots to determine their position based on their location from the emitter.
[25] Vision based location estimation system by . (2017, Jun 2.). CN107356252B. [Online] Available: https://patents.google.com/patent/CN107356252B/en?oq=CN107356252B

This patent describes using multiple Kalman filters to process data from an ultra-wideband positioning system, pressure sensors, temperature sensors, and inertial measurement data, to obtain precise location data. This process could be used to combine several onboard sensors already implemented on the Romi with the prototype to further increase the precision of positional data.

## Appendices

## QFD House of Quality


## Functional Decomposition


## Gantt Chart


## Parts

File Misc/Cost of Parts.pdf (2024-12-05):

Part | Cost [$] | Purchased By
Micro HDMI to HDMI cable (3ft) | 8.95 | Sponsor
TwoZoh Micro HDMI to HDMI cable (15ft) | 13.99 | Sponsor
Raspberry Pi Camera Module 3 Standard - 12MP Autofocus | 25.00 | Sponsor
Raspberry Pi 4 model B-8GB RAM x2 | 150.00 | Sponsor
Official Raspberry Pi Power Supply 5.1V 3A with USB C | 7.95 | Sponsor
SD/MicroSD Memory Card - 16GB Class 10 - Adapter Included | 19.95 | Sponsor
Official Raspberry Pi 4 Case Fan and Heatsink | 5.00 | Sponsor
Twozoh 4K micro HDMI to HDMI 60Hz 1080p | 13.99 | Sponsor
USB Charger Block OKRAY 2-pack 18W | 8.99 | Sponsor
Baiwwa USB C Cable, USB A to type C Cable Charger | 8.98 | Sponsor
1/4''-20 1" Machine Screws | 1.36 | Team
M2.5 10mm Machine Screws | 10.86 | Team
M2 10mm Machine Screws | 9.99 | Team
M2 Nuts | 0.00 | Team
M2.5 Threaded Inserts | 8.99 | Team
1/8" Mushroom Head Toggle Bolt Anchors | 8.48 | Team
Overture Black & White PLA 2pack, 1kg spools | 28.99 | Team
Parts Total | 331.47
Project Budget | 500.00

Pseudo GPS for Romi Final Budget

Part | Cost [$] | Purchased By
Raspberry Pi Screen, ROAMDOM 10.1'' Touchscreen Monitor, 1024 x 600 | 99.99 | Team
Logitech MK270 Wireless Keyboard and Mouse Combo | 27.99 | Team
Beikell SD Card Reader, Dual Connector USB C Memory Card Reader Adapter | 7.59 | Team
Parts Total | 135.57
Current Budget | 0.00

Recommended Parts

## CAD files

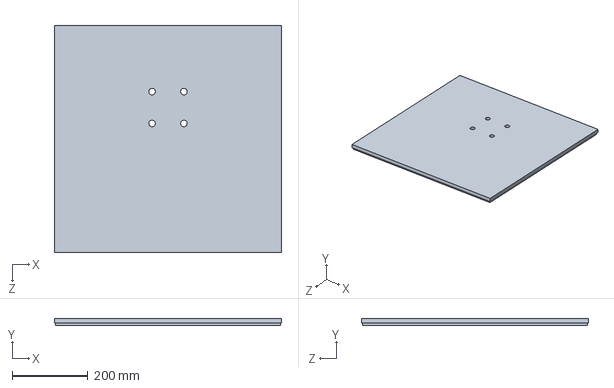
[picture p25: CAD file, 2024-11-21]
CAD Files/SolidWorks Parts/Assemblies/10 Ceiling Tile Assy.SLDASM
600.1 x 19.1 x 600.1 mm

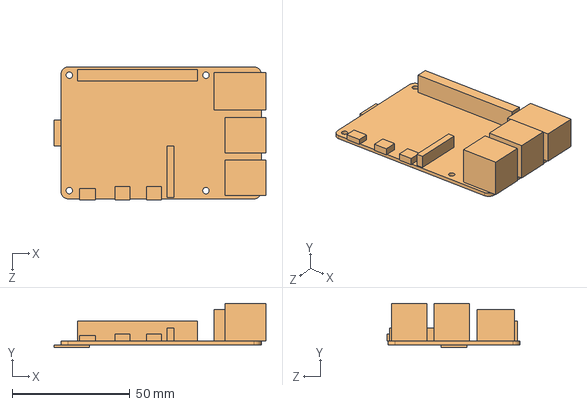
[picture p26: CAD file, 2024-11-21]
CAD Files/SolidWorks Parts/Assemblies/220 Microcontroller Assy.SLDASM
90.0 x 18.7 x 56.5 mm
2210 RaspPi_4B
2220 MicroSD

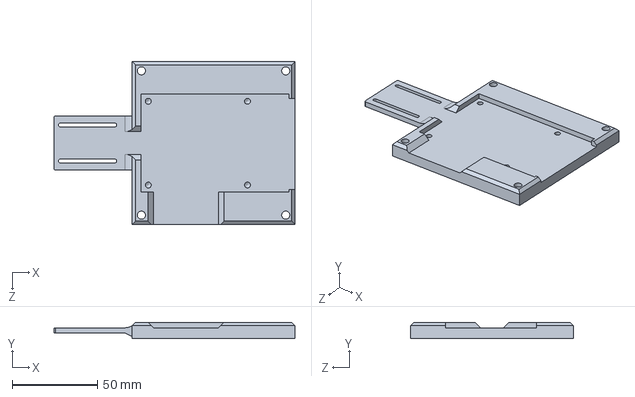
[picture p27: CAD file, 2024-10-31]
CAD Files/SolidWorks Parts/210 MainHousing.SLDPRT
141.0 x 9.53 x 95.2 mm

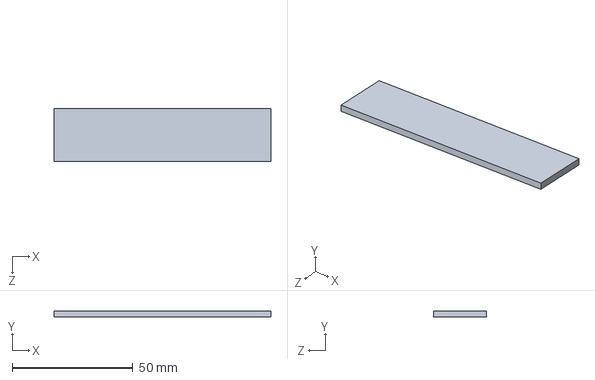
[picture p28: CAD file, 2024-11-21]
CAD Files/SolidWorks Parts/Miscellaneous/badge.SLDPRT
90.0 x 2.54 x 22.0 mm

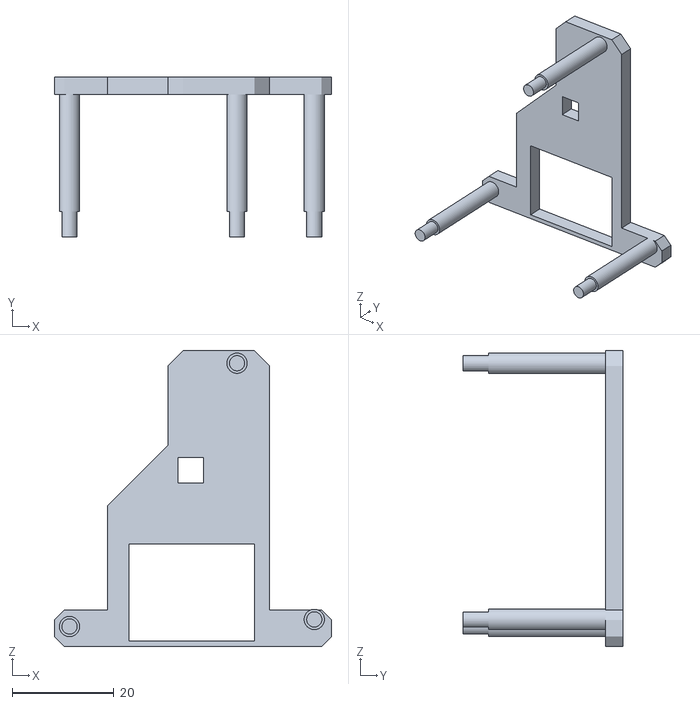
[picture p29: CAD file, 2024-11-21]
CAD Files/SolidWorks Parts/Nucleo Mount/NucleoMount_V4_Tall.STL
54.5 x 31.5 x 58.2

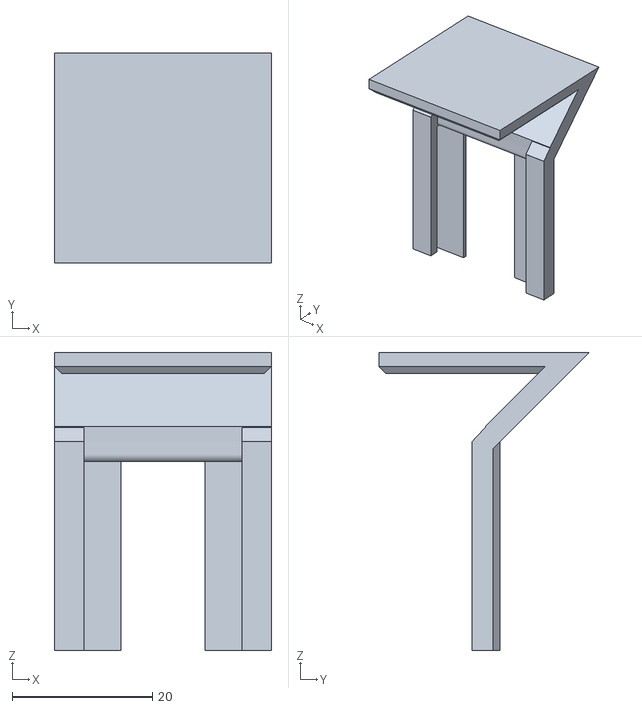
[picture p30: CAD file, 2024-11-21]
CAD Files/STL Files/PiCamFrame.STL
31.0 x 30.0 x 42.6

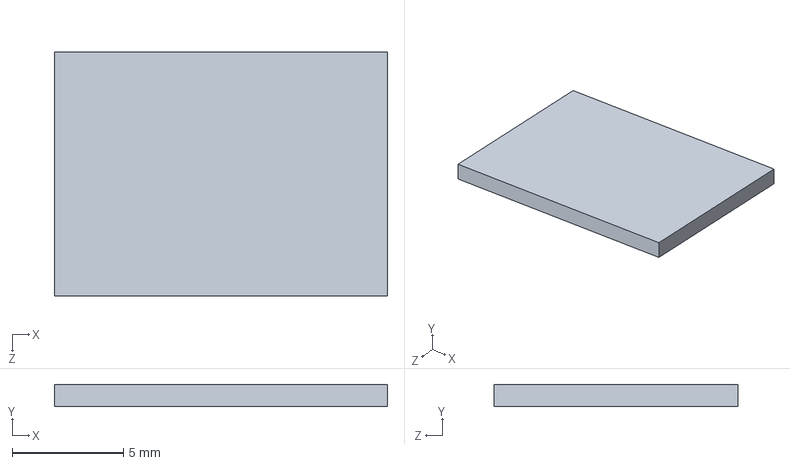
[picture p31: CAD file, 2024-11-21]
CAD Files/SolidWorks Parts/2220 MicroSD.SLDPRT
15.0 x 1.00 x 11.0 mm

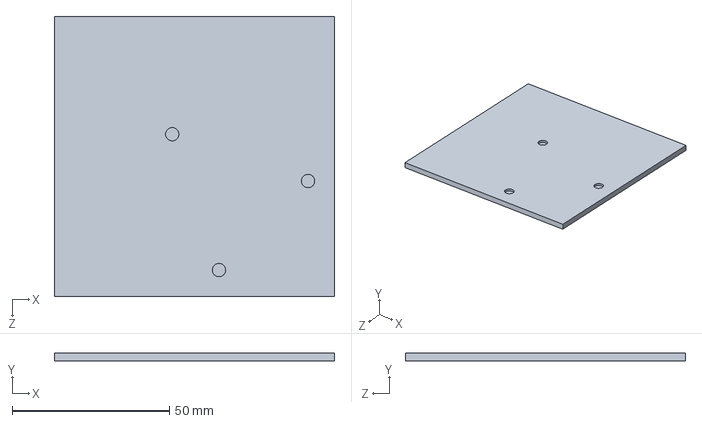
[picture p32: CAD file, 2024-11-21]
CAD Files/SolidWorks Parts/ArucoPart/ArcuoPart_V4_Magnet.SLDPRT
88.9 x 2.54 x 88.9 mm

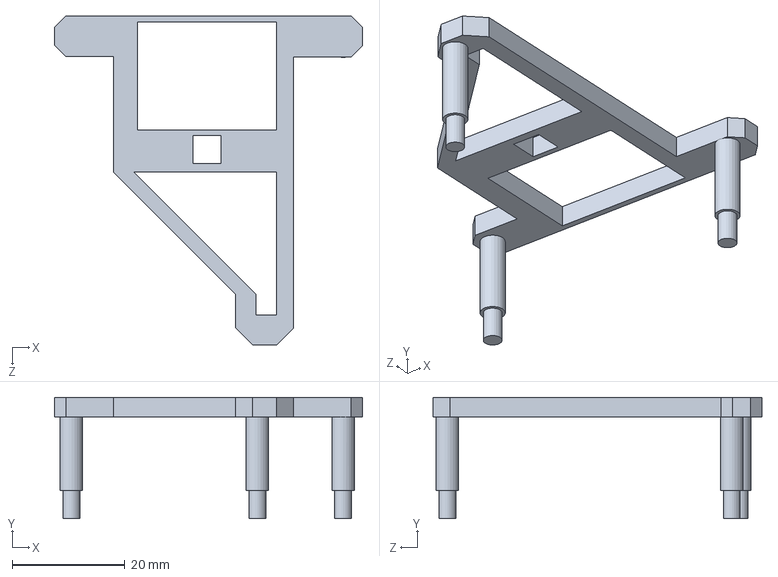
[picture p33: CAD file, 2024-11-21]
CAD Files/SolidWorks Parts/Nucleo Mount/Nucleomount_Copy.SLDPRT
54.5 x 21.5 x 58.2 mm

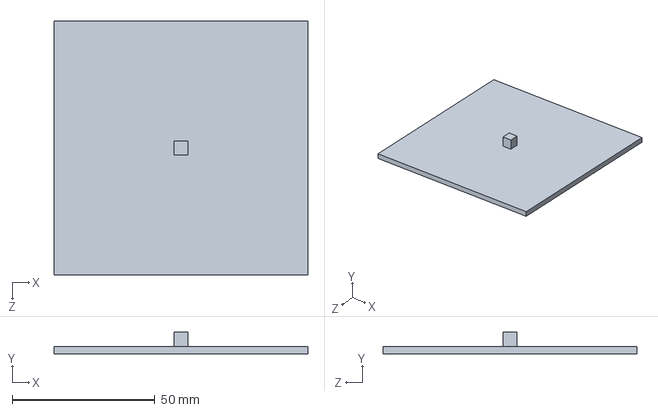
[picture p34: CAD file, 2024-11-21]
CAD Files/SolidWorks Parts/ArucoPart/arucoPart_V5_Object.SLDPRT
88.9 x 7.54 x 88.9 mm

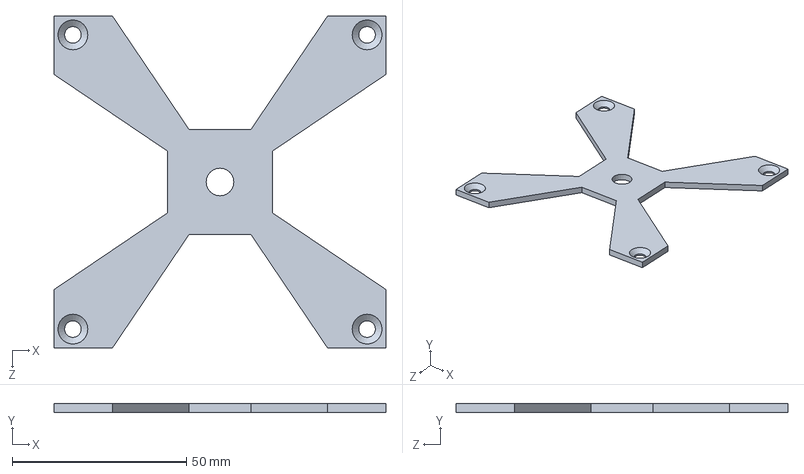
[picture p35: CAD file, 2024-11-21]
CAD Files/SolidWorks Parts/Miscellaneous/RomiB DrillJig.SLDPRT
95.2 x 2.54 x 95.2 mm

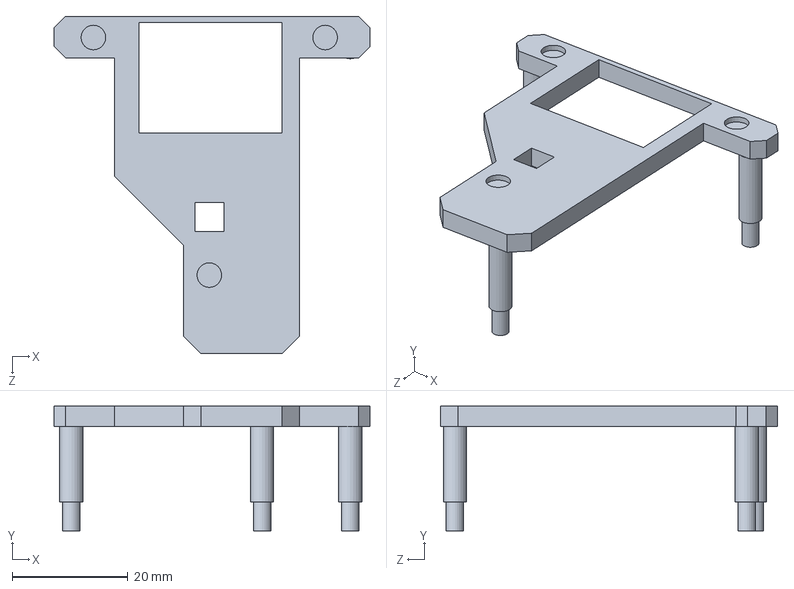
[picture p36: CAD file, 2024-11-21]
CAD Files/SolidWorks Parts/Nucleo Mount/NucleoMount_V4.SLDPRT
54.5 x 21.5 x 58.2 mm

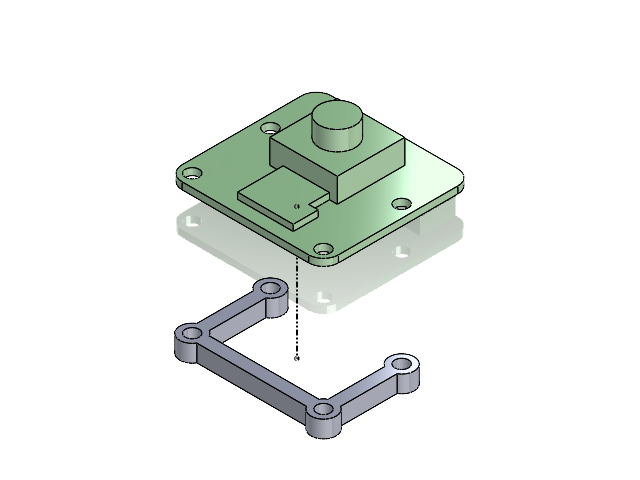
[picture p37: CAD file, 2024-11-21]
CAD Files/SolidWorks Parts/Assemblies/230 Camera Assy.SLDASM
2310 Raspi_Cam_Module_3
2320 CamSpacer

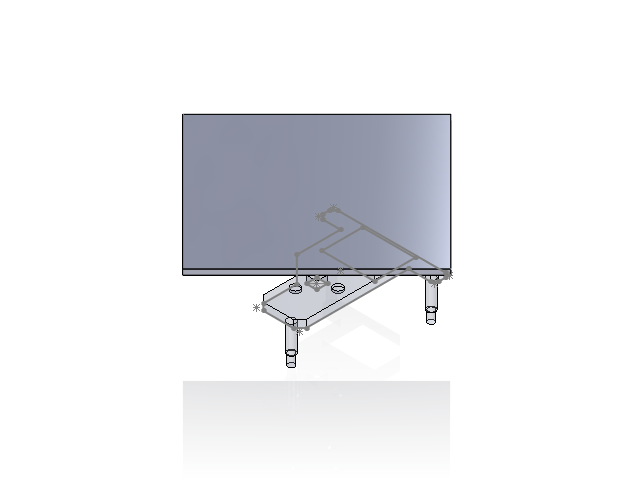
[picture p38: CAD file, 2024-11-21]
CAD Files/SolidWorks Parts/Miscellaneous/NewRomiStuff.SLDASM
NucleoMount_V3
ArcuoPart_V3

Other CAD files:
CAD Files/SolidWorks Parts/Assemblies/Testbench_stands.SLDASM
CAD Files/SolidWorks Parts/2210 RaspPi_4B.SLDPRT
CAD Files/STL Files/210 FrameBase.STL
CAD Files/SolidWorks Parts/110 CeilingTile.SLDPRT
CAD Files/STL Files/CamSpacer.STL
CAD Files/STL Files/FrameBase.STL
CAD Files/SolidWorks Parts/2310 Raspi_Cam_Module_3.SLDPRT
CAD Files/SolidWorks Parts/2320 CamSpacer.SLDPRT
CAD Files/SolidWorks Parts/ArucoPart/ArcuoPart_V2.SLDPRT
CAD Files/SolidWorks Parts/ArucoPart/ArcuoPart_V3.SLDPRT
CAD Files/SolidWorks Parts/ArucoPart/ArcuoPart_V3.STL
CAD Files/SolidWorks Parts/ArucoPart/ArcuoPart_V4_Magnet.STL
CAD Files/SolidWorks Parts/ArucoPart/arucoPart.SLDPRT
CAD Files/SolidWorks Parts/Fasteners/120 Tapping Inserts for Softwood.SLDPRT
CAD Files/SolidWorks Parts/Fasteners/230 .75-25l Pan Head Phillips Screw.SLDPRT
CAD Files/SolidWorks Parts/Fasteners/240 M2.5 Socket Head Screw.SLDPRT
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

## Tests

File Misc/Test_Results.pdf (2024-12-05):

| | Computer | Actual | z [mm] | Difference | Abs Diff | % ERROR
Run 1 | x [mm] | 86 | 81 | 15 | 5 | 5 | 6.17284
| y [mm] | 369 | 370 | | -1 | 1 | 0.27027
Run 2 | x [mm] | 605 | 590 | 113 | 15 | 15 | 2.542373
| y [mm] | 202 | 190 | | 12 | 12 | 6.315789
Run 3 | x [mm] | 536 | 534 | 50 | 2 | 2 | 0.374532
| y [mm] | 378 | 380 | | -2 | 2 | 0.526316
Run 4 | x [mm] | 24 | 35 | 113 | -11 | 11 | 31.42857
| y [mm] | 53 | 60 | | -7 | 7 | 11.66667
Run 5 | x [mm] | 117 | 122 | 50 | -5 | 5 | 4.098361
| y [mm] | 460 | 463 | | -3 | 3 | 0.647948
| | | | avg | 0.5 | 6.3
stDevt | 8.195527 4.831609
Computer | Actual | Difference Abs Diff % ERROR
Run 1 | x [mm] | 310 | 296 | 14 | 14 | 4.72973
| y [mm] | 95 | 85 | 10 | 10 | 11.76471
Run 2 | x [mm] | 192 | 178 | 14 | 14 | 7.865169
| y [mm] | 339 | 330 | 9 | 9 | 2.727273
Run 3 | x [mm] | 232 | 225 | 7 | 7 | 3.111111
| y [mm] | 144 | 150 | -6 | 6 | 4
Run 4 | x [mm] | 208 | 195 | 13 | 13 | 6.666667
| y [mm] | 231 | 220 | 11 | 11 | 5
Run 5 | x [mm] | 141 | 135 | 6 | 6 | 4.444444
| y [mm] | 232 | 215 | 17 | 17 | 7.906977
avg | 9.5 | 10.7
stDevt | 6.416126 3.772709

Distance Test @ Various Heights

Distance Test @ Constant Heights (Markers placed on romi)[z = 105mm]

Computer | Actual | Difference Abs Diff
| Run 1 | x [mm] | 7 | 0 | 7 | 7
| | y [mm] | 362 | 361 | 1 | 1
| Run 2 | x [mm] | 89 | 90 | -1 | 1
| | y [mm] | 2 | 0 | 2 | 2
| Run 3 | x [mm] | 139 | 137 | 2 | 2
| | y [mm] | 46 | 42 | 4 | 4
| Run 4 | x [mm] | 35 | 30 | 5 | 5
| | y [mm] | 236 | 242 | -6 | 6
*angled | Run 5 | x [mm] | 455 | 443 | 12 | 12
| | y [mm] | 248 | 255 | -7 | 7
avg | 1.9 | 4.7
stDevt | 5.704774 3.465705
StdevM | 1 mm
AVG | 7.233333333 [mm]
Usys | 7.112586652 [mm]

Mat uncertainty

Distance Test @ Constant Heights (Markers placed on table) [z=0mm]

%ERROR | Computer [°]Actual [°]
DIV0 | Run 1
0.277008
| Run 2
1.111111
DIV0 | Run 3
1.459854 | Run 4
9.52381
| Run 5
16.66667
2.479339

2.708804
2.745098

Orientation Angle Test

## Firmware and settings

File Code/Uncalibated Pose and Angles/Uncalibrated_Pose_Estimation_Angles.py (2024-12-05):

"""
Senior Design Project: ArUco Marker Detection and Pose Estimation
===========================================================

Authors: 
- Conor Schott
- Gabriel Coria
- Emmanuel Baez
- Owen Guinane

Aruco Marker Detection and Pose Estimation
===========================================
This script detects ArUco markers in a video stream captured by a Raspberry Pi camera.
It calculates the relative position and orientation of detected markers with respect 
to a designated origin marker. The relative position is expressed in millimeters, and 
the orientation is given in degrees.

Key Features:
-------------
1. Real-time marker detection and pose estimation.
2. Dynamic origin setup using a specific marker (Marker ID 1).
3. Adjustable calibration factor for fine-tuning measurements.
4. Outputs marker position and orientation at a controlled 5 Hz rate.

Dependencies:
-------------
- Python 3.x
- OpenCV
- NumPy
- Picamera2 (for Raspberry Pi camera interface)

Notes:
------
- Press `+` or `-` to adjust the calibration factor during runtime.
- Press `q` to quit the detection process.
"""

import cv2
import numpy as np
import time
from picamera2 import Picamera2
import cv2.aruco as aruco

class ArucoMarkers:
    """
    Class for detecting ArUco markers and estimating their pose in real-time.

    This class utilizes the Raspberry Pi camera to detect ArUco markers in a video 
    stream, calculate their relative position and orientation with respect to a 
    designated origin marker (Marker ID 1), and display the results on the video stream.
    """

    def __init__(self, marker_width_pixels=100):
        """
        Constructor for the ArucoMarkers class.
        
        @param marker_width_pixels The width of the marker in pixels for scaling purposes.
        """
        # Initialize marker parameters and camera configuration
        self.marker_width_pixels = marker_width_pixels  # Width of the marker in pixels for scaling
        self.piCam = Picamera2()  # Initialize the Raspberry Pi camera
        self.piCam.preview_configuration.main.size = (640, 480)  # Set the camera resolution (640x480)
        self.piCam.preview_configuration.align()  # Ensure proper configuration alignment
        self.piCam.configure("preview")  # Configure the camera for preview mode
        self.piCam.start()  # Start the camera for capturing frames

        # Parameters for calibration and pose estimation
        self.marker_size_in_inches = 3.5  # Physical size of the marker in inches
        self.calibration_factor = 2.755  # Initial calibration factor for scaling purposes
        self.origin_position = None  # Store the position of the origin marker (Marker ID 1)
        self.origin_rotation_matrix = None  # Store the rotation matrix of the origin marker

        # Example camera calibration parameters: intrinsic camera matrix and distortion coefficients
        self.camera_matrix = np.array([
            [482.3, 0, 322.5],  # Focal lengths and principal point (cx, cy)
            [0, 486.2, 244.8],
            [0, 0, 1]
        ])
        self.dist_coeffs = np.array([0.1, -0.02, 0, 0, 0])  # Distortion coefficients for the camera

    def detect_aruco_markers(self, aruco_type=aruco.DICT_6X6_100):
        """
        Detects ArUco markers in the camera's video stream and calculates their pose 
        relative to the origin marker (Marker ID 1).
        
        @param aruco_type Predefined ArUco dictionary type (default: DICT_6X6_100).
        """
        # Load the ArUco dictionary and set the detection parameters
        aruco_dict = aruco.getPredefinedDictionary(aruco_type)  # Predefined ArUco dictionary
        aruco_params = aruco.DetectorParameters()  # Default ArUco detection parameters

        # Define 3D coordinates of the marker corners in the world frame
        world_points = np.array([
            [0., 0., 0.],  # Bottom-left corner
            [1., 0., 0.],  # Bottom-right corner
            [1., 1., 0.],  # Top-right corner
            [0., 1., 0.]   # Top-left corner
        ])

        # Timer to control output frequency (5 Hz)
        last_print_time = time.time()

        while True:
            # Capture a frame from the camera and convert it to grayscale
            frame = self.piCam.capture_array()  # Capture an image from the Pi camera
            frame = cv2.cvtColor(frame, cv2.COLOR_RGB2BGR)  # Convert the image to BGR format (OpenCV standard)
            gray = cv2.cvtColor(frame, cv2.COLOR_BGR2GRAY)  # Convert to grayscale for ArUco detection

            # Detect markers in the frame
            corners, ids, _ = aruco.detectMarkers(gray, aruco_dict, parameters=aruco_params)

            if ids is not None:  # If markers are detected
                # Draw detected markers on the frame
                frame = aruco.drawDetectedMarkers(frame, corners, ids)

                # Iterate through all detected markers
                for i, corner in enumerate(corners):
                    marker_id = ids[i][0]  # Extract the marker ID
                    # Solve the PnP problem to estimate pose (rotation and translation)
                    _, rvec, tvec = cv2.solvePnP(world_points, corner[0], self.camera_matrix, self.dist_coeffs)

                    # Calculate the center of the marker
                    center_x = int(np.mean(corner[0][:, 0]))  # Average x-coordinate of the marker corners
                    center_y = int(np.mean(corner[0][:, 1]))  # Average y-coordinate of the marker corners

                    # Set the origin marker (Marker ID 1) for relative calculations
                    if marker_id == 1:
                        self.origin_position = (center_x, center_y)  # Set origin position as the center of marker 1
                        self.origin_rotation_matrix, _ = cv2.Rodrigues(rvec)  # Store the origin's rotation matrix

                    if self.origin_position is not None and self.origin_rotation_matrix is not None:
                        # Calculate the relative position in pixels, then convert to mm
                        rel_x_pixels = center_x - self.origin_position[0]
                        rel_y_pixels = center_y - self.origin_position[1]
                        x_mm = rel_x_pixels * (self.marker_size_in_inches / self.marker_width_pixels) * self.calibration_factor * 25.4
                        y_mm = rel_y_pixels * (self.marker_size_in_inches / self.marker_width_pixels) * self.calibration_factor * 25.4

                        # Compute the relative rotation angle using Rodrigues' formula
                        current_rotation_matrix, _ = cv2.Rodrigues(rvec)
                        relative_rotation_matrix = np.dot(current_rotation_matrix, self.origin_rotation_matrix.T)
                        angle_rad = np.arccos((np.trace(relative_rotation_matrix) - 1) / 2)
                        angle_deg = np.degrees(angle_rad)

                        # Print marker information at a 5 Hz rate (every 0.2 seconds)
                        current_time = time.time()
                        if current_time - last_print_time >= 0.2:
                            print(f"Marker ID: {marker_id} - X: {x_mm:.2f} mm, Y: {y_mm:.2f} mm, Angle: {angle_deg:.2f}°")
                            last_print_time = current_time

                        # Display marker position and orientation on the frame
                        label = f"ID {marker_id} | X: {x_mm:.2f} mm, Y: {y_mm:.2f} mm, Angle: {angle_deg:.2f}°"
                        cv2.putText(frame, label, (center_x, center_y - 20), cv2.FONT_HERSHEY_SIMPLEX, 0.5, (0, 255, 0), 1)

                    # Draw coordinate axes for each detected marker
                    cv2.drawFrameAxes(frame, self.camera_matrix, self.dist_coeffs, rvec, tvec, 1)

                # Handle runtime calibration adjustments and exit command
                key = cv2.waitKey(1) & 0xFF
                if key == ord('+'):  # Increase calibration factor
                    self.calibration_factor += 0.1
                elif key == ord('-'):  # Decrease calibration factor
                    self.calibration_factor = max(0.1, self.calibration_factor - 0.1)
                elif key == ord('q'):  # Exit the detection loop
                    break

            # Display the video frame with detected markers and pose information
            cv2.imshow('Aruco Detection', frame)

        # Clean up resources after exiting
        self.piCam.stop()  # Stop the Pi camera
        cv2.destroyAllWindows()  # Close the OpenCV window


# Example usage of the ArucoMarkers class
if __name__ == "__main__":
    # Create an instance of the ArucoMarkers class
    aruco_markers = ArucoMarkers()
    # Start the marker detection process
    aruco_markers.detect_aruco_markers()

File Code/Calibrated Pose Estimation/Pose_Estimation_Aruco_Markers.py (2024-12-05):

"""
@file aruco_marker_detection.py
@brief This script implements ArUco marker generation, detection, and pose estimation using a Raspberry Pi and OpenCV.

@details
This project focuses on real-time ArUco marker tracking and pose estimation. It includes functionalities for:
- Generating ArUco markers.
- Detecting ArUco markers in real-time using the Raspberry Pi camera.
- Estimating marker pose relative to a dynamically updating origin marker.

@authors
- Conor Schott
- Gabriel Coria
- Emmanuel Baez
- Owen Guinane

@dependencies
- Python 3.x
- OpenCV
- NumPy
- Matplotlib
- Picamera2 library

@date November 21, 2024
"""

from enum import Enum
import cv2
import numpy as np
import os
import matplotlib.pyplot as plt
from picamera2 import Picamera2

class ArucoType(Enum):
    """
    @brief Enum class to define supported ArUco marker types.

    This enum provides predefined ArUco marker types that can be used for marker generation and detection.
    """
    DICT_4X4_50 = cv2.aruco.DICT_4X4_50
    DICT_4X4_100 = cv2.aruco.DICT_4X4_100
    DICT_4X4_250 = cv2.aruco.DICT_4X4_250
    DICT_4X4_1000 = cv2.aruco.DICT_4X4_1000
    DICT_5X5_50 = cv2.aruco.DICT_5X5_50
    DICT_5X5_100 = cv2.aruco.DICT_5X5_100
    DICT_5X5_250 = cv2.aruco.DICT_5X5_250
    DICT_5X5_1000 = cv2.aruco.DICT_5X5_1000
    DICT_6X6_50 = cv2.aruco.DICT_6X6_50
    DICT_6X6_100 = cv2.aruco.DICT_6X6_100
    DICT_6X6_250 = cv2.aruco.DICT_6X6_250
    DICT_6X6_1000 = cv2.aruco.DICT_6X6_1000
    DICT_7X7_50 = cv2.aruco.DICT_7X7_50
    DICT_7X7_100 = cv2.aruco.DICT_7X7_100
    DICT_7X7_250 = cv2.aruco.DICT_7X7_250
    DICT_7X7_1000 = cv2.aruco.DICT_7X7_1000
    DICT_ARUCO_ORIGINAL = cv2.aruco.DICT_ARUCO_ORIGINAL

class ArucoMarkers:
    """
    @class ArucoMarkers
    @brief Class to manage ArUco marker operations, including generation, detection, and pose estimation.

    @param marker_width_pixels The width of the marker in pixels. Default is 100 pixels.
    """
    def __init__(self, marker_width_pixels=100):
        """
        @brief Initializes the ArUcoMarkers object and configures the Raspberry Pi camera.

        @param marker_width_pixels The width of the marker in pixels. Default is 100 pixels.
        """
        self.dir = os.getcwd()  # Working directory
        self.piCam = Picamera2()  # Raspberry Pi Camera
        self.piCam.preview_configuration.main.size = (640, 480)
        self.piCam.preview_configuration.align()
        self.piCam.configure("preview")
        self.piCam.start()
        self.marker_width_pixels = marker_width_pixels  # Marker size in pixels
        self.origin_position = None  # Position of reference marker (Marker ID 1)
        self.smoothed_positions = {}  # Smoothed positions for each marker

    def generate_aruco_marker(self, aruco_type, marker_id, show_image=False):
        """
        @brief Generates and saves an ArUco marker as an image file.

        @param aruco_type The type of ArUco marker (from the ArucoType enum).
        @param marker_id The ID of the marker to generate.
        @param show_image Boolean flag to display the generated marker. Default is False.
        
        @note The marker is saved as `aruco_marker.png` in the current working directory.
        """
        print("Generating ArUco Marker...")
        aruco_dict = cv2.aruco.getPredefinedDictionary(aruco_type.value)
        marker_image = np.zeros((self.marker_width_pixels, self.marker_width_pixels), dtype=np.uint8)
        marker_image = cv2.aruco.drawMarker(aruco_dict, marker_id, self.marker_width_pixels)

        # Add border around the marker
        border_width = 5
        marker_image = cv2.copyMakeBorder(
            marker_image,
            border_width, border_width, border_width, border_width,
            cv2.BORDER_CONSTANT,
            value=[255, 255, 255]
        )
        cv2.imwrite(os.path.join(self.dir, "aruco_marker.png"), marker_image)

        if show_image:
            plt.imshow(marker_image, cmap="gray")
            plt.show()

    def aruco_marker_pose_estimation(self, aruco_type, camera_matrix, dist_coeffs):
        """
        @brief Detects ArUco markers in a live video stream, estimates their pose, and computes
               their position relative to a dynamic origin (Marker ID 1).

        @param aruco_type The type of ArUco marker (from the ArucoType enum).
        @param camera_matrix The camera matrix for intrinsic parameters.
        @param dist_coeffs The distortion coefficients for the camera.
        
        @note This function runs indefinitely, detecting and estimating the pose of ArUco markers 
              in real-time. Press `+` to increase the calibration factor, `-` to decrease, and `q` to quit.
        """
        print("Detecting ArUco Marker...")

        aruco_dict = cv2.aruco.getPredefinedDictionary(aruco_type.value)
        aruco_params = cv2.aruco.DetectorParameters()

        marker_size_in_inches = 3.51
        calibration_factor = 2.754
        alpha_x = 0.05  # Smoothing factor for x-axis
        alpha_y = 0.65  # Smoothing factor for y-axis

        while True:
            frame = self.piCam.capture_array()
            frame = cv2.cvtColor(frame, cv2.COLOR_RGB2BGR)

            # Detect ArUco markers
            frame_gray = cv2.cvtColor(frame, cv2.COLOR_BGR2GRAY)
            corners, ids, _ = cv2.aruco.detectMarkers(frame_gray, aruco_dict, parameters=aruco_params)

            if ids is not None:
                frame = cv2.aruco.drawDetectedMarkers(frame, corners, ids)

                for i, corner in enumerate(corners):
                    marker_id = ids[i][0]
                    center_x = int(np.mean(corner[0][:, 0]))
                    center_y = int(np.mean(corner[0][:, 1]))

                    if marker_id == 1:
                        self.origin_position = (center_x, center_y)

                    if self.origin_position is not None:
                        rel_x_pixels = center_x - self.origin_position[0]
                        rel_y_pixels = center_y - self.origin_position[1]

                        x_mm = rel_x_pixels * (marker_size_in_inches / (self.marker_width_pixels + 10)) * calibration_factor * 25.4
                        y_mm = rel_y_pixels * (marker_size_in_inches / (self.marker_width_pixels + 10)) * calibration_factor * 25.4

                        if marker_id not in self.smoothed_positions:
                            self.smoothed_positions[marker_id] = (x_mm, y_mm)
                        else:
                            prev_x, prev_y = self.smoothed_positions[marker_id]
                            x_mm = alpha_x * x_mm + (1 - alpha_x) * prev_x
                            y_mm = alpha_y * y_mm + (1 - alpha_y) * prev_y
                            self.smoothed_positions[marker_id] = (x_mm, y_mm)

                        print(f"Marker ID: {marker_id} - X: {x_mm:.2f} mm, Y: {y_mm:.2f} mm")
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
